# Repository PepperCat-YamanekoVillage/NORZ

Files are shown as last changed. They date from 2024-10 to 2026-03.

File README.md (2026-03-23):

# NORZ

NORZ is a project to create a Z80-compatible CPU using only NOR gates.

</br>

The project is progressing according to the following roadmap:
- [x] Draft the CPU design based on the Z80 specifications
- [x] Write the Verilog code
- [x] Debug the Verilog code
- [x] Implement the design on boards
- [x] Make a test board
- [x] Test the test board
- [ ] Debug the boards

</br>

### My blogs (ja)

[Gates consisting of NOR](https://yamanekovillage.com/articles/norz_1/)

[Modules consisting of NOR](https://yamanekovillage.com/articles/norz_2/)

[NORZ(Z80)\'s architecture](https://yamanekovillage.com/articles/norz_3/)

[NORZ on Verilog](https://yamanekovillage.com/articles/norz_4/)

[Debuging Verilog codes](https://yamanekovillage.com/articles/norz_5/)

[Design PCBs](https://yamanekovillage.com/articles/norz_6/)

[Make a test board (Failed)](https://yamanekovillage.com/articles/norz_7/)

</br>

## Confirmed instructions in Verilog

### 8-Bit Load Group
- [x] LD r,r’
- [x] LD r,n
- [x] LD r,(HL)
- [x] LD r,(IX+d)
- [x] LD r,(IY+d)
- [x] LD (HL),r
- [x] LD (IX+d),r
- [x] LD (IY+d),r
- [x] LD (HL),n
- [x] LD (IX+d),n
- [x] LD (IY+d),n
- [x] LD A,(BC)
- [x] LD A,(DE)
- [x] LD A,(nn)
- [x] LD (BC),A
- [x] LD (DE),A
- [x] LD (nn),A
- [x] LD A,I
- [x] LD A,R
- [x] LD I,A
- [x] LD R,A

### 16-Bit Load Group
- [x] LD dd,nn
- [x] LD IX,nn
- [x] LD IY,nn
- [x] LD HL,(nn)
- [x] LD dd,(nn)
- [x] LD IX,(nn)
- [x] LD IY,(nn)
- [x] LD (nn),HL
- [x] LD (nn),dd
- [x] LD (nn),IX
- [x] LD (nn),IY
- [x] LD SP,HL
- [x] LD SP,IX
- [x] LD SP,IY
- [x] PUSH qq
- [x] PUSH IX
- [x] PUSH IY
- [x] POP qq
- [x] POP IX
- [x] POP IY

### Exchange, Block Transfer, and Search Group
- [x] EX DE,HL
- [x] EX AF,AF
- [x] EXX
- [x] EX (SP),HL
- [x] EX (SP),IX
- [x] EX (SP),IY
- [x] LDI
- [x] LDIR
- [x] LDD
- [x] LDDR
- [x] CPI
- [x] CPIR
- [x] CPD
- [x] CPDR

### 8-Bit Arithmetic Group
- [x] ADD A,r
- [x] ADD A,n
- [x] ADD A,(HL)
- [x] ADD A,(IX+d)
- [x] ADD A,(IY+d)
- [x] ADC A,r
- [x] ADC A,n
- [x] ADC A,(HL)
- [x] ADC A,(IX+d)
- [x] ADC A,(IY+d)
- [x] SUB r
- [x] SUB n
- [x] SUB (HL)
- [x] SUB (IX+d)
- [x] SUB (IY+d)
- [x] SBC r
- [x] SBC n
- [x] SBC (HL)
- [x] SBC (IX+d)
- [x] SBC (IY+d)
- [x] AND r
- [x] AND n
- [x] AND (HL)
- [x] AND (IX+d)
- [x] AND (IY+d)
- [x] OR r
- [x] OR n
- [x] OR (HL)
- [x] OR (IX+d)
- [x] OR (IY+d)
- [x] XOR r
- [x] XOR n
- [x] XOR (HL)
- [x] XOR (IX+d)
- [x] XOR (IY+d)
- [x] CP r
- [x] CP n
- [x] CP (HL)
- [x] CP (IX+d)
- [x] CP (IY+d)
- [x] INC r
- [x] INC (HL)
- [x] INC (IX+d)
- [x] INC (IY+d)
- [x] DEC r
- [x] DEC (HL)
- [x] DEC (IX+d)
- [x] DEC (IY+d)

### General-Purpose Arithmetic and CPU Control Groups
- [x] DAA
- [x] CPL
- [x] NEG
- [x] CCF
- [x] SCF
- [x] NOP
- [x] HALT
- [x] DI
- [x] EI
- [x] IM 0
- [x] IM 1
- [x] IM 2

### 16-Bit Arithmetic Group
- [x] ADD HL,ss
- [x] ADC HL,ss
- [x] SBC HL,ss
- [x] ADD IX,pp
- [x] ADD IY,rr
- [x] INC ss
- [x] INC IX
- [x] INC IY
- [x] DEC ss
- [x] DEC IX
- [x] DEC IY

### Rotate and Shift Group
- [x] RLCA
- [x] RLA
- [x] RRCA
- [x] RRA
- [x] RLC r
- [x] RLC (HL)
- [x] RLC (IX+d)
- [x] RLC (IY+d)
- [x] RL r
- [x] RL (HL)
- [x] RL (IX+d)
- [x] RL (IY+d)
- [x] RRC r
- [x] RRC (HL)
- [x] RRC (IX+d)
- [x] RRC (IY+d)
- [x] RR r
- [x] RR (HL)
- [x] RR (IX+d)
- [x] RR (IY+d)
- [x] SLA r
- [x] SLA (HL)
- [x] SLA (IX+d)
- [x] SLA (IY+d)
- [x] SRA r
- [x] SRA (HL)
- [x] SRA (IX+d)
- [x] SRA (IY+d)
- [x] SRL r
- [x] SRL (HL)
- [x] SRL (IX+d)
- [x] SRL (IY+d)
- [x] RLD
- [x] RRD

### Bit Set, Reset, and Test Group
- [x] BIT b,r
- [x] BIT b,(HL)
- [x] BIT b,(IX+d)
- [x] BIT b,(IY+d)
- [x] SET b,r
- [x] SET b,(HL)
- [x] SET b,(IX+d)
- [x] SET b,(IY+d)
- [x] RES b,r
- [x] RES b,(HL)
- [x] RES b,(IX+d)
- [x] RES b,(IY+d)

### Jump Group
- [x] JP nn
- [x] JP cc,nn
- [x] JR e
- [x] JR C,e
- [x] JR NC,e
- [x] JR Z,e
- [x] JR NZ,e
- [x] JP (HL)
- [x] JP (IX)
- [x] JP (IY)
- [x] DJNZ e

### Call and Return Group
- [x] CALL nn
- [x] CALL cc,nn
- [x] RET
- [x] RET cc
- [x] RETI
- [x] RETN
- [x] RST p

### Input and Output Group
- [x] IN A,(n)
- [x] IN r,(C)
- [x] INI
- [x] INIR
- [x] IND
- [x] INDR
- [x] OUT (n),A
- [x] OUT (C),r
- [x] OUTI
- [x] OTIR
- [x] OUTD
- [x] OTDR

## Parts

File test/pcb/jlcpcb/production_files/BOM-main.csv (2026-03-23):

Comment | Designator | Footprint | LCSC | Quantity
0.5K-DHQX-60PWB | U1 | FPC-SMD_60P-P0.50_HDGC_0.5K-DHQX-60PWB | C5292476 | 1
Screw_Terminal_01x02 | J2 | TerminalBlock_bornier-2_P5.08mm |  | 1
MEGA BOTTOM | J1 | MEGA2560_PRO_MINI |  | 1

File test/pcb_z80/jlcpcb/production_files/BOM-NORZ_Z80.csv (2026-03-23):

Comment | Designator | Footprint | LCSC | Quantity
0.5K-DHQX-60PWB | U1 | FPC-SMD_60P-P0.50_HDGC_0.5K-DHQX-60PWB | C5292476 | 1
22nF | C2 | C_0603_1608Metric |  | 1
100nF | C1 | C_0603_1608Metric |  | 1
Z84C00xxP | U2 | DIP-40_W15.24mm |  | 1

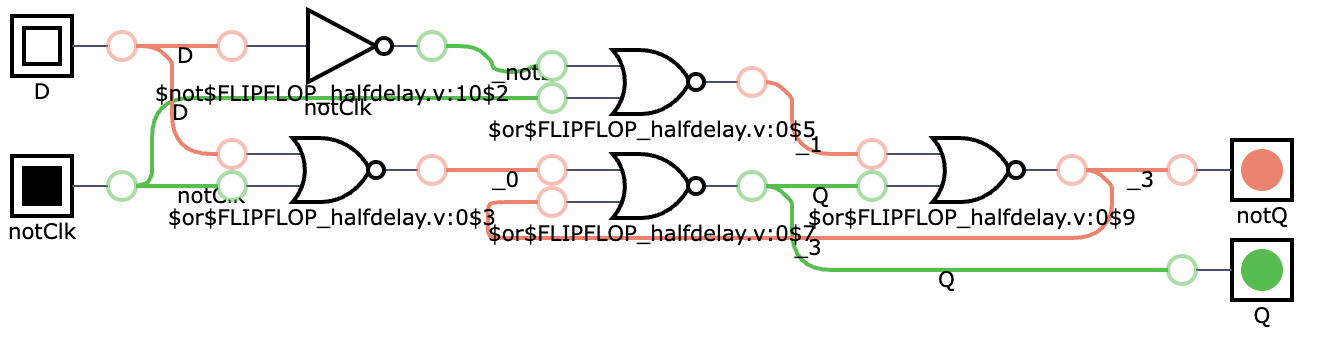
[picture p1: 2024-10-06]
flipflop/parts/.halfdelay.png

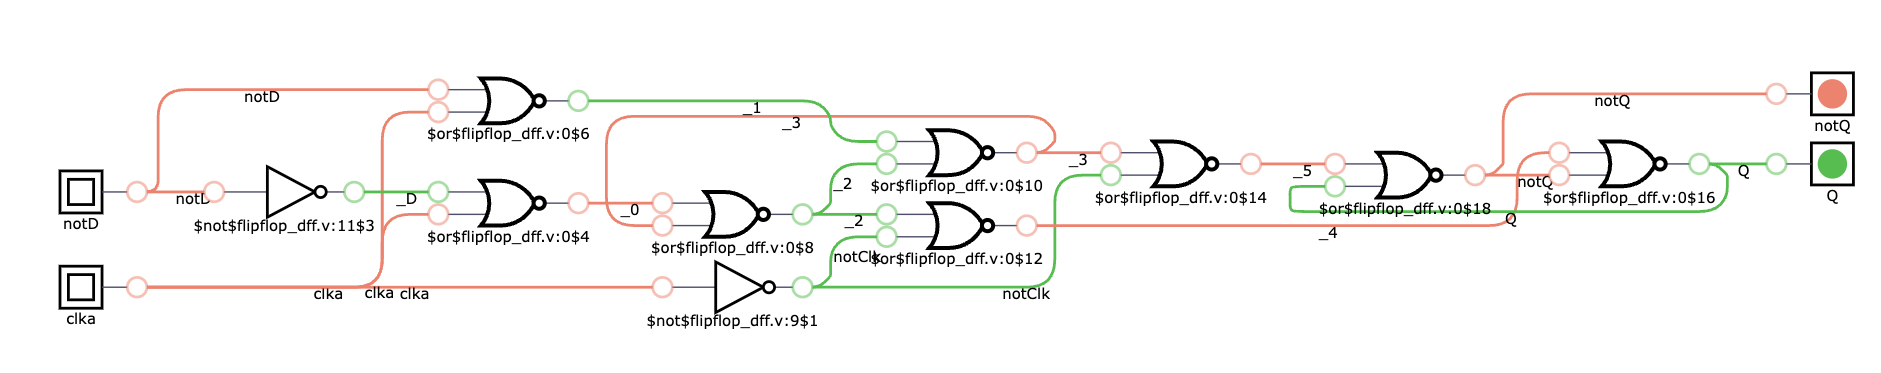
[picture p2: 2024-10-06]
verilog/flipflop/parts/.dff.png

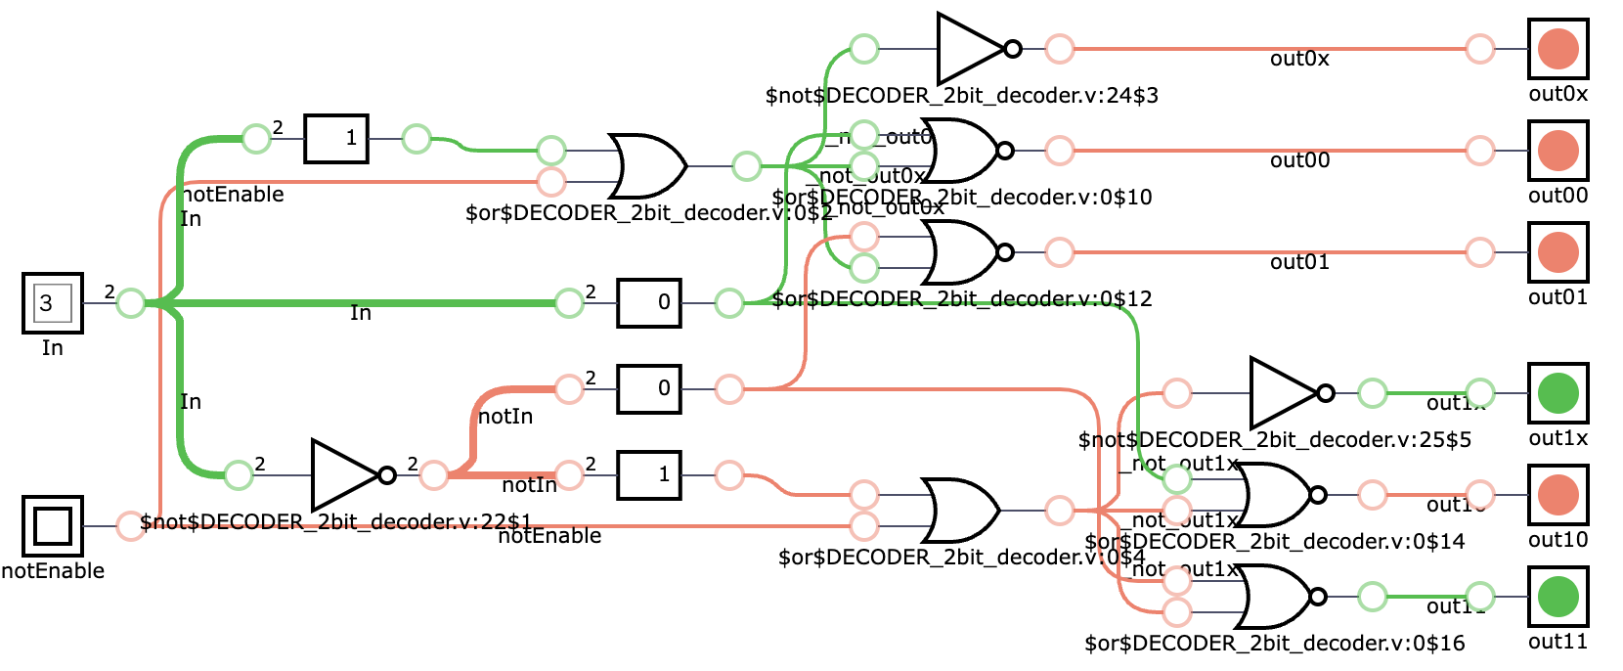
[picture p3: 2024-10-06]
verilog/decoder/parts/.2bit_decoder.png

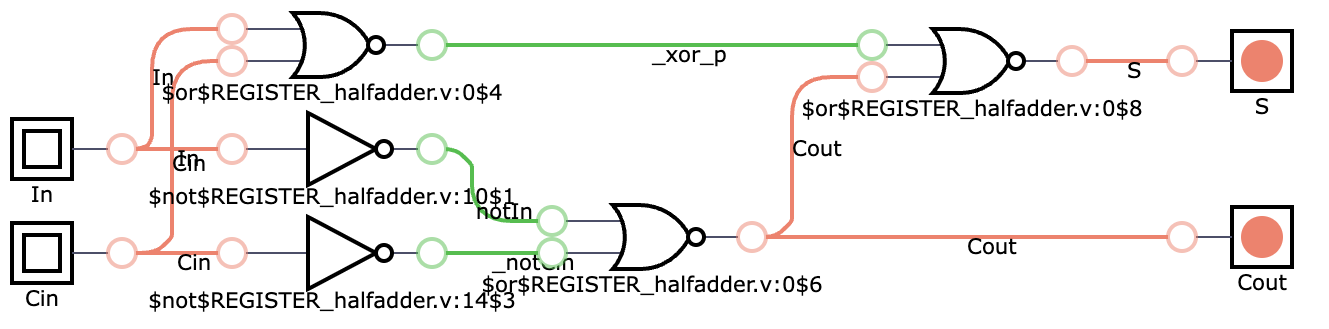
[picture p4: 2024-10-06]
register/parts/.half_adder_inc.png

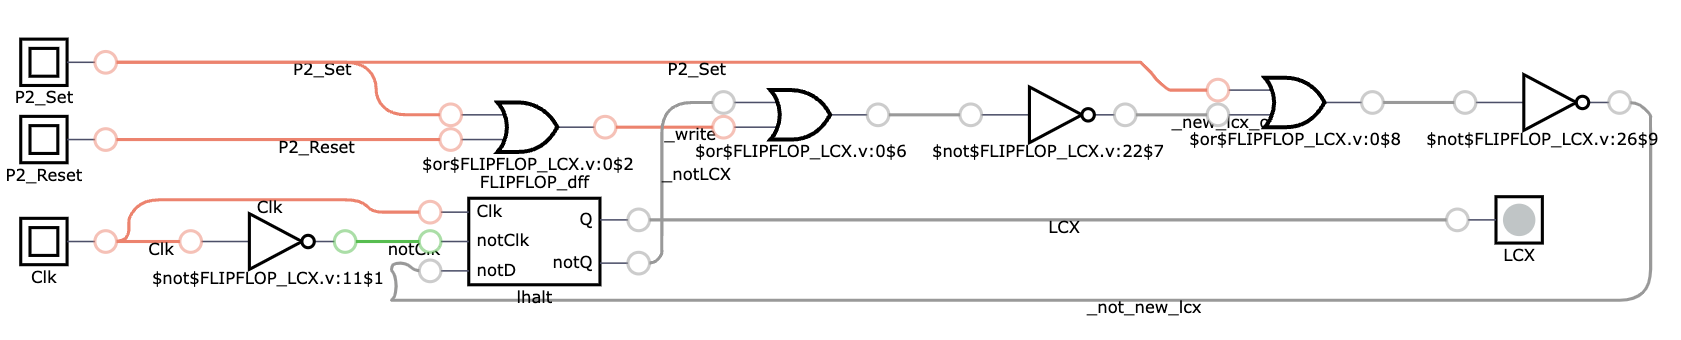
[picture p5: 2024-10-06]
verilog/flipflop/parts/.dff_LCX.png

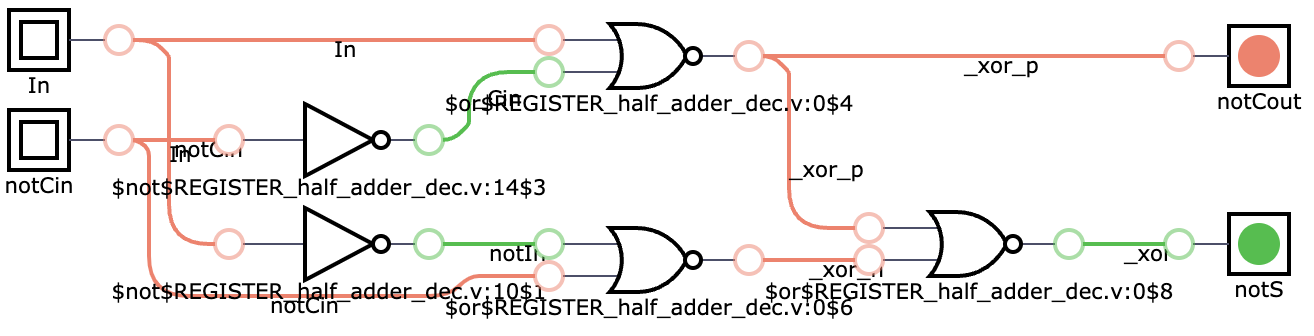
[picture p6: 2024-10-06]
register/parts/.half_adder_dec.png

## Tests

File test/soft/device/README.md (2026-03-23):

# Device Firmware (PlatformIO)

Arduino Mega2560 firmware that hosts a Z80 bus cycle runner.

## Build

```bash
cd device
pio run
```

## Upload

```bash
cd device
pio run --target upload
pio device monitor --baud 115200
```

## Serial Commands

- `PING`
- `RESET`
- `DATA_SRC <D|O>`
- `CLK_US <halfCycleUs>`
- `CLEAR [byteHex]`
- `LOAD <addrHex> <b0> <b1> ...`
- `RUN <cyclesDec>`
- `STEP`
- `SNAP`
- `MEM <addrHex> <lenHex>`
- `TRACE`
- `WTRACE`

All responses are single-line ASCII.

`DATA_SRC` selects which bus is used when reading Z80 write data:
- `D`: read from D0-D7 pins (default)
- `O`: read from Dout0-Dout7 pins

`CLK_US` sets half-cycle length in microseconds (default: 20).

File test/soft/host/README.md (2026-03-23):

# Host Runner (Mega2560 + Z80)

This script drives the Mega2560 firmware over serial and runs text tests from `_test/tests_txt`.

## Setup

```bash
cd host
python -m venv .venv
source .venv/bin/activate
pip install -r requirements.txt
```

## Run

```bash
python run_tests.py --port /dev/ttyACM0 --tests ../_test/tests_txt --filter MEGA --data-src D --half-cycle-us 20 --cycles 300
```

## Make Targets

```bash
make run                 # default run
make test                # run all tests, save to log-test-all.txt
make expand              # run by category, save log25-*.txt
make debug               # focused IO/BIT run, save log34-*.txt
```

You can override serial port and options:

```bash
make test PORT=/dev/cu.usbserial-1140 RUN_OPTS="--half-cycle-us 100 --cycles 300"
```

## Notes

- Current runner evaluates `PC=` assertions via M1 trace and memory assertions via `(<addr>)=<value>`.
- Use `--strict-reg` to enforce register/flag assertions (`A..L`, `IX/IY/SP`, `F`, `FlagS/Z/H/PV/N/C`, `I`, `R`, `LHALT`) via firmware command `CAPREG`.
- Default mode keeps compatibility with previous behavior (memory + PC assertions), and does not fail tests when snapshot capture is unavailable.
- `IMFa`, `IMFb`, `IFF1`, `IFF2` are parsed but not enforced by default because they are not directly exposed by the current snapshot protocol.
- `--data-src` selects write-data input source (`D`=D bus default, `O`=Dout bus).
- `--half-cycle-us` controls bus speed; increase this if write/read sampling is unstable.

Debug write trace for `MEGA/LD (nn),HL write`:

```bash
python run_tests.py --port /dev/ttyACM0 --filter MEGA --debug-ldnnhl
```

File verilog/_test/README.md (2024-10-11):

# How2debug

install coctb
```
py -m venv .venv
source .venv/bin/activate
py -m pip install cocotb
```

run make
```
make
```

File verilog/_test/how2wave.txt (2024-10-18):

rm -f sim_build;source .venv/bin/activate;make>log.txt;gtkwave sim_build/NORZ.fst

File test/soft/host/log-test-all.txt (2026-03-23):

PASS AR16/ADC HL,ss.txt
PASS AR16/ADD HL,ss.txt
PASS AR16/ADD IX,pp.txt
PASS AR16/ADD IY,rr.txt
PASS AR16/DEC IX.txt
PASS AR16/DEC IY.txt
PASS AR16/DEC ss.txt
PASS AR16/INC IX.txt
PASS AR16/INC IY.txt
PASS AR16/INC ss.txt
PASS AR16/SBC HL,ss.txt
PASS AR8/ADC A,(HL).txt
PASS AR8/ADC A,(IX+d).txt
PASS AR8/ADC A,(IY+d).txt
PASS AR8/ADC A,n.txt
PASS AR8/ADC A,r.txt
PASS AR8/ADD A,(HL).txt
PASS AR8/ADD A,(IX+d).txt
PASS AR8/ADD A,(IY+d).txt
PASS AR8/ADD A,n.txt
PASS AR8/ADD A,r.txt
PASS AR8/AND (HL).txt
PASS AR8/AND (IX+d).txt
PASS AR8/AND (IY+d).txt
PASS AR8/AND n.txt
PASS AR8/AND r.txt
PASS AR8/CP (HL).txt
PASS AR8/CP (IX+d).txt
PASS AR8/CP (IY+d).txt
PASS AR8/CP n.txt
PASS AR8/CP r.txt
PASS AR8/DEC (HL).txt
PASS AR8/DEC (IX+d).txt
PASS AR8/DEC (IY+d).txt
PASS AR8/DEC r.txt
PASS AR8/INC (HL).txt
PASS AR8/INC (IX+d).txt
PASS AR8/INC (IY+d).txt
PASS AR8/INC r.txt
PASS AR8/OR (HL).txt
PASS AR8/OR (IX+d).txt
PASS AR8/OR (IY+d).txt
PASS AR8/OR n.txt
PASS AR8/OR r.txt
PASS AR8/SBC (HL).txt
PASS AR8/SBC (IX+d).txt
PASS AR8/SBC (IY+d).txt
PASS AR8/SBC n.txt
PASS AR8/SBC r.txt
PASS AR8/SUB (HL).txt
PASS AR8/SUB (IX+d).txt
PASS AR8/SUB (IY+d).txt
PASS AR8/SUB n.txt
PASS AR8/SUB r.txt
PASS AR8/XOR (HL).txt
PASS AR8/XOR (IX+d).txt
PASS AR8/XOR (IY+d).txt
PASS AR8/XOR n.txt
PASS AR8/XOR r.txt
PASS BIT/BIT b,(HL).txt
PASS BIT/BIT b,(IX+d).txt
PASS BIT/BIT b,(IY+d).txt
PASS BIT/BIT b,r.txt
PASS BIT/RES b,(HL).txt
PASS BIT/RES b,(IX+d).txt
PASS BIT/RES b,(IY+d).txt
PASS BIT/RES b,r.txt
PASS BIT/SET b,(HL).txt
PASS BIT/SET b,(IX+d).txt
PASS BIT/SET b,(IY+d).txt
PASS BIT/SET b,r.txt
PASS CR/CALL cc,nn - c.txt
PASS CR/CALL cc,nn - nc.txt
PASS CR/CALL cc,nn - npv.txt
PASS CR/CALL cc,nn - ns.txt
PASS CR/CALL cc,nn - nz.txt
PASS CR/CALL cc,nn - pv.txt
PASS CR/CALL cc,nn - s.txt
PASS CR/CALL cc,nn - z.txt
PASS CR/CALL nn.txt
PASS CR/RET cc - c.txt
PASS CR/RET cc - nc.txt
PASS CR/RET cc - npv.txt
PASS CR/RET cc - ns.txt
PASS CR/RET cc - nz.txt
PASS CR/RET cc - pv.txt
PASS CR/RET cc - s.txt
PASS CR/RET cc - z.txt
PASS CR/RET.txt
PASS CR/RETI.txt
PASS CR/RST p - 0.txt
PASS CR/RST p - 1.txt
PASS CR/RST p - 2.txt
PASS CR/RST p - 3.txt
PASS CR/RST p - 4.txt
PASS CR/RST p - 5.txt
PASS CR/RST p - 6.txt
PASS CR/RST p - 7.txt
PASS EX/CPD.txt
PASS EX/CPDR.txt
PASS EX/CPI.txt
PASS EX/CPIR.txt
PASS EX/EX (SP),HL.txt
PASS EX/EX (SP),IX.txt
PASS EX/EX (SP),IY.txt
PASS EX/EX AF,AF.txt
PASS EX/EX DE,HL.txt
PASS EX/EXX.txt
PASS EX/LDD.txt
PASS EX/LDDR.txt
PASS EX/LDI.txt
PASS EX/LDIR.txt
PASS GAR/CCF.txt
PASS GAR/CPL.txt
PASS GAR/DAA.txt
PASS GAR/DI.txt
PASS GAR/EI.txt
PASS GAR/HALT.txt
PASS GAR/IM 0.txt
PASS GAR/IM 1.txt
PASS GAR/IM 2.txt
PASS GAR/NEG.txt
PASS GAR/NOP.txt
PASS GAR/SCF.txt
PASS IO/IN A,(n).txt
PASS IO/IN r,(C).txt
PASS IO/IND.txt
PASS IO/INDR.txt
PASS IO/INI.txt
PASS IO/INIR.txt
PASS IO/OTDR.txt
PASS IO/OTIR.txt
PASS IO/OUT (C),r.txt
PASS IO/OUT (n),A.txt
PASS IO/OUTD.txt
PASS IO/OUTI.txt
PASS JP/DJNZ e.txt
PASS JP/JP (HL).txt
PASS JP/JP (IX).txt
PASS JP/JP (IY).txt
PASS JP/JP cc,nn - c.txt
PASS JP/JP cc,nn - nc.txt
PASS JP/JP cc,nn - npv.txt
PASS JP/JP cc,nn - ns.txt
PASS JP/JP cc,nn - nz.txt
PASS JP/JP cc,nn - pv.txt
PASS JP/JP cc,nn - s.txt
PASS JP/JP cc,nn - z.txt
PASS JP/JP nn.txt
PASS JP/JR C,e.txt
PASS JP/JR NC,e.txt
PASS JP/JR NZ,e.txt
PASS JP/JR Z,e.txt
PASS JP/JR e - minus.txt
PASS JP/JR e - plus.txt
PASS LD16/LD (nn),HL.txt
PASS LD16/LD (nn),IX.txt
PASS LD16/LD (nn),IY.txt
PASS LD16/LD (nn),dd.txt
PASS LD16/LD HL,(nn).txt
PASS LD16/LD IX,(nn).txt
PASS LD16/LD IX,nn.txt
PASS LD16/LD IY,(nn).txt
PASS LD16/LD IY,nn.txt
PASS LD16/LD SP,HL.txt
PASS LD16/LD SP,IX.txt
PASS LD16/LD SP,IY.txt
PASS LD16/LD dd,(nn).txt
PASS LD16/LD dd,nn.txt
PASS LD16/PUSH IX | POP IX.txt
PASS LD16/PUSH IY | POP IY.txt
PASS LD16/PUSH qq | POP qq.txt
PASS LD8/LD (BC),A.txt
PASS LD8/LD (DE),A.txt
PASS LD8/LD (HL),n.txt
PASS LD8/LD (HL),r.txt
PASS LD8/LD (IX+d),n.txt
PASS LD8/LD (IX+d),r.txt
PASS LD8/LD (IY+d),n.txt
PASS LD8/LD (IY+d),r.txt
PASS LD8/LD (nn),A.txt
PASS LD8/LD A,(BC).txt
PASS LD8/LD A,(DE).txt
PASS LD8/LD A,(nn).txt
PASS LD8/LD A,I.txt
PASS LD8/LD A,R.txt
PASS LD8/LD I,A.txt
PASS LD8/LD R,A.txt
PASS LD8/LD r,(HL).txt
PASS LD8/LD r,(IX+d).txt
PASS LD8/LD r,(IY+d).txt
PASS LD8/LD r,n.txt
PASS LD8/LD r,r.txt
PASS MEGA/JP loop 0000.txt
PASS MEGA/LD (nn),HL write.txt
PASS ROT/RL (HL).txt
PASS ROT/RL (IX+d).txt
PASS ROT/RL (IY+d).txt
PASS ROT/RL r.txt
PASS ROT/RLA.txt
PASS ROT/RLC (HL).txt
PASS ROT/RLC (IX+d).txt
PASS ROT/RLC (IY+d).txt
PASS ROT/RLC r.txt
PASS ROT/RLCA.txt
PASS ROT/RLD.txt
PASS ROT/RR (HL).txt
PASS ROT/RR (IX+d).txt
PASS ROT/RR (IY+d).txt
PASS ROT/RR r.txt
PASS ROT/RRA.txt
PASS ROT/RRC (HL).txt
PASS ROT/RRC (IX+d).txt
PASS ROT/RRC (IY+d).txt
PASS ROT/RRC r.txt
PASS ROT/RRCA.txt
PASS ROT/RRD.txt
PASS ROT/SLA (HL).txt
PASS ROT/SLA (IX+d).txt
PASS ROT/SLA (IY+d).txt
PASS ROT/SLA r.txt
PASS ROT/SRA (HL).txt
PASS ROT/SRA (IX+d).txt
PASS ROT/SRA (IY+d).txt
PASS ROT/SRA r.txt
PASS ROT/SRL (HL).txt
PASS ROT/SRL (IX+d).txt
PASS ROT/SRL (IY+d).txt
PASS ROT/SRL r.txt
PASS _INTERRUPT/BUSRQ.txt
PASS _INTERRUPT/INT - 0CALL.txt
PASS _INTERRUPT/INT - 0RST.txt
PASS _INTERRUPT/INT - 1.txt
PASS _INTERRUPT/INT - 2.txt
PASS _INTERRUPT/NMI - di.txt
PASS _INTERRUPT/NMI - ei.txt
PASS _SAMPLE/divide.txt
PASS _SAMPLE/multiply.txt

Result: passed=238 failed=0

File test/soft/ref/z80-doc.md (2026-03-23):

---
title: NORだけでZ80互換CPUをつくる 〜 仕様決め 〜
description: NORゲートだけでCPUをつくるため、Z80の仕様を確認し、どんなふうに回路をつくればちゃんと動作しそうかの仕様決めをしました
slug: norz_3
thumbnail_url: "https://media.yamanekovillage.com/norz_3"
category: create
createdAt: 2024/08/25
modifiedAt: 2025/06/13
writer: 山椒ねこまんま
draft: false
---

1ヶ月ほどかかってようやく仕様が決まりました。いや〜長かった。202コも命令があるのでなかなか大変でしたよ。

もっとも、まだ実際に回路をつくってテストしたわけではないのでこれから変更される可能性もあるのですがね。

なお、仕様決定にあたり以下の本やページを参考にしました。とても参考になりました。ありがとうございます。\
{{< link
    "https://ndlsearch.ndl.go.jp/books/R100000002-I000001418670"
    "https://ndlsearch.ndl.go.jp/books/R100000002-I000001418670">}}\
{{< link
    "http://www.zilog.com/docs/z80/um0080.pdf"
    "http://www.zilog.com/docs/z80/um0080.pdf">}}\
{{< link
    "https://www.zilog.com/docs/z80/ps0178.pdf"
    "https://www.zilog.com/docs/z80/ps0178.pdf">}}\
{{< link
    "http://www.z80.info/zip/z80-interrupts.pdf"
    "http://www.z80.info/zip/z80-interrupts.pdf">}}\
{{< link
    "http://www.kazumi-kikou.com/pdf/TMPZ84C00AP.pdf"
    "http://www.kazumi-kikou.com/pdf/TMPZ84C00AP.pdf">}}\
{{< link
    "http://www.maroon.dti.ne.jp/youkan/mz700/z80cycle.html"
    "http://www.maroon.dti.ne.jp/youkan/mz700/z80cycle.html">}}\
{{< link
    "http://mydocuments.g2.xrea.com/html/p6/z80ref.html"
    "http://mydocuments.g2.xrea.com/html/p6/z80ref.html">}}

{{< toc >}}
インターフェース{#interface}
レジスタ{#register}
  - 公式{#rg-official}
  - 非公式{#rg-unofficial}
フリップフロップ{#flipflop}
  - 公式{#ff-official}
  - 非公式{#ff-unofficial}
パスフラグ{#pathflag}
  - レジスタ{#pf-pr}
  - フラグ{#pf-pf}
  - フリップフロップ{#pf-p2}
  - ALU{#pf-pa}
  - インターフェース{#pf-pi}
  - 半遅延インターフェース{#pf-phi}
  - 遅延{#pf-pai}
ALU{#alu}
  - 演算{#alu-operation}
  - 出力バス{#alu-bus}
デコーダ{#decoder}
  - 標準サイクル{#basecycle}
    - M1{#bc-m1}
    - MR{#bc-mr}
    - MA{#bc-ma}
    - R{#bc-r}
    - RA{#bc-ra}
    - W{#bc-w}
    - I{#bc-i}
    - O{#bc-o}
  - 割り込みサイクル{#interruptcycle}
    - マスク可能割り込み{#ic-int}
    - マスク不能割り込み{#ic-nmi}
    - バス要求{#ic-busrq}
    - リセット{#ic-reset}
  - 命令{#instruction}
    - 8bitデータ移動{#in-8ld}
      - LD r,r’{#in-LDrr}
      - LD r,n{#in-LDrn}
      - LD r,(HL){#in-LDrqHLp}
      - LD r,(IX+d){#in-LDrqIXtdp}
      - LD r,(IY+d){#in-LDrqIYtdp}
      - LD (HL),r{#in-LDqHLpr}
      - LD (IX+d),r{#in-LDqIXtdpr}
      - LD (IY+d),r{#in-LDqIYtdpr}
      - LD (HL),n{#in-LDqHLpn}
      - LD (IX+d),n{#in-LDqIXtdpn}
      - LD (IY+d),n{#in-LDqIYtdpn}
      - LD A,(BC){#in-LDAqBCp}
      - LD A,(DE){#in-LDAqDEp}
      - LD A,(nn){#in-LDAqnnp}
      - LD (BC),A{#in-LDqBCpA}
      - LD (DE),A{#in-LDqDEpA}
      - LD (nn),A{#in-LDqnnpA}
      - LD A,I{#in-LDAI}
      - LD A,R{#in-LDAR}
      - LD I,A{#in-LDIA}
      - LD R,A{#in-LDRA}
    - 16bitデータ移動{#in-16ld}
      - LD dd,nn{#in-LDddnn}
      - LD IX,nn{#in-LDIXnn}
      - LD IY,nn{#in-LDIYnn}
      - LD HL,(nn){#in-LDHLqnnp}
      - LD dd,(nn){#in-LDddqnnp}
      - LD IX,(nn){#in-LDIXqnnp}
      - LD IY,(nn){#in-LDIYqnnp}
      - LD (nn),HL{#in-LDqnnpHL}
      - LD (nn),dd{#in-LDqnnpdd}
      - LD (nn),IX{#in-LDqnnpIX}
      - LD (nn),IY{#in-LDqnnpIY}
      - LD SP,HL{#in-LDSPHL}
      - LD SP,IX{#in-LDSPIX}
      - LD SP,IY{#in-LDSPIY}
      - PUSH qq{#in-PUSHqq}
      - PUSH IX{#in-PUSHIX}
      - PUSH IY{#in-PUSHIY}
      - POP qq{#in-POPqq}
      - POP IX{#in-POPIX}
      - POP IY{#in-POPIY}
    - 交換・ブロック転送および検索{#in-ex}
      - EX DE,HL{#in-EXDEHL}
      - EX AF,A’F’{#in-EXAFAF}
      - EXX{#in-EXX}
      - EX (SP),HL{#in-EXqSPpHL}
      - EX (SP),IX{#in-EXqSPpIX}
      - EX (SP),IY{#in-EXqSPpIY}
      - LDI{#in-LDI}
      - LDIR{#in-LDIR}
      - LDD{#in-LDD}
      - LDDR{#in-LDDR}
      - CPI{#in-CPI}
      - CPIR{#in-CPIR}
      - CPD{#in-CPD}
      - CPDR{#in-CPDR}
    - 8bit算術・論理演算{#in-8ari}
      - ADD A,r{#in-ADDAr}
      - ADD A,n{#in-ADDAn}
      - ADD A,(HL){#in-ADDAqHLp}
      - ADD A,(IX+d){#in-ADDAqIXtdp}
      - ADD A,(IY+d){#in-ADDAqIYtdp}
      - ADC A,r{#in-ADCAr}
      - ADC A,n{#in-ADCAn}
      - ADC A,(HL){#in-ADCAqHLp}
      - ADC A,(IX+d){#in-ADCAqIXtdp}
      - ADC A,(IY+d){#in-ADCAqIYtdp}
      - SUB A,r{#in-SUBAr}
      - SUB A,n{#in-SUBAn}
      - SUB A,(HL){#in-SUBAqHLp}
      - SUB A,(IX+d){#in-SUBAqIXtdp}
      - SUB A,(IY+d){#in-SUBAqIYtdp}
      - SBC A,r{#in-SBCAr}
      - SBC A,n{#in-SBCAn}
      - SBC A,(HL){#in-SBCAqHLp}
      - SBC A,(IX+d){#in-SBCAqIXtdp}
      - SBC A,(IY+d){#in-SBCAqIYtdp}
      - AND A,r{#in-ANDAr}
      - AND A,n{#in-ANDAn}
      - AND A,(HL){#in-ANDAqHLp}
      - AND A,(IX+d){#in-ANDAqIXtdp}
      - AND A,(IY+d){#in-ANDAqIYtdp}
      - OR A,r{#in-ORAr}
      - OR A,n{#in-ORAn}
      - OR A,(HL){#in-ORAqHLp}
      - OR A,(IX+d){#in-ORAqIXtdp}
      - OR A,(IY+d){#in-ORAqIYtdp}
      - XOR A,r{#in-XORAr}
      - XOR A,n{#in-XORAn}
      - XOR A,(HL){#in-XORAqHLp}
      - XOR A,(IX+d){#in-XORAqIXtdp}
      - XOR A,(IY+d){#in-XORAqIYtdp}
      - CP A,r{#in-CPAr}
      - CP A,n{#in-CPAn}
      - CP A,(HL){#in-CPAqHLp}
      - CP A,(IX+d){#in-CPAqIXtdp}
      - CP A,(IY+d){#in-CPAqIYtdp}
      - INC r{#in-INCr}
      - INC (HL){#in-INCqHLp}
      - INC (IX+d){#in-INCqIXtdp}
      - INC (IY+d){#in-INCqIYtdp}
      - DEC r{#in-DECr}
      - DEC (HL){#in-DECqHLp}
      - DEC (IX+d){#in-DECqIXtdp}
      - DEC (IY+d){#in-DECqIYtdp}
    - 汎用算術演算およびCPU制御{#in-gpa}
      - DAA{#in-DAA}
      - CPL{#in-CPL}
      - NEG{#in-NEG}
      - CCF{#in-CCF}
      - SCF{#in-SCF}
      - NOP{#in-NOP}
      - HALT{#in-HALT}
      - DI{#in-DI}
      - EI{#in-EI}
      - IM 0{#in-IM0}
      - IM 1{#in-IM1}
      - IM 2{#in-IM2}
    - 16bit算術演算{#in-16ari}
      - ADD HL,ss{#in-ADDHLss}
      - ADC HL,ss{#in-ADCHLss}
      - SBC HL,ss{#in-SBCHLss}
      - ADD IX,pp{#in-ADDIXpp}
      - ADD IY,rr{#in-ADDIYrr}
      - INC ss{#in-INCss}
      - INC IX{#in-INCIX}
      - INC IY{#in-INCIY}
      - DEC ss{#in-DECss}
      - DEC IX{#in-DECIX}
      - DEC IY{#in-DECIY}
    - 循環および桁移動{#in-rot}
      - RLCA{#in-RLCA}
      - RLA{#in-RLA}
      - RRCA{#in-RRCA}
      - RRA{#in-RRA}
      - RLC r{#in-RLCr}
      - RLC (HL){#in-RLCqHLp}
      - RLC (IX+d){#in-RLCqIXtdp}
      - RLC (IY+d){#in-RLCqIYtdp}
      - RL r{#in-RLr}
      - RL (HL){#in-RLqHLp}
      - RL (IX+d){#in-RLqIXtdp}
      - RL (IY+d){#in-RLqIYtdp}
      - RRC r{#in-RRCr}
      - RRC (HL){#in-RRCqHLp}
      - RRC (IX+d){#in-RRCqIXtdp}
      - RRC (IY+d){#in-RRCqIYtdp}
      - RR r{#in-RRr}
      - RR (HL){#in-RRqHLp}
      - RR (IX+d){#in-RRqIXtdp}
      - RR (IY+d){#in-RRqIYtdp}
      - RLC r{#in-RLCr}
      - RLC (HL){#in-RLCqHLp}
      - RLC (IX+d){#in-RLCqIXtdp}
      - RLC (IY+d){#in-RLCqIYtdp}
      - SLA r{#in-SLAr}
      - SLA (HL){#in-SLAqHLp}
      - SLA (IX+d){#in-SLAqIXtdp}
      - SLA (IY+d){#in-SLAqIYtdp}
      - SRA r{#in-SRAr}
      - SRA (HL){#in-SRAqHLp}
      - SRA (IX+d){#in-SRAqIXtdp}
      - SRA (IY+d){#in-SRAqIYtdp}
      - SRL r{#in-SRLr}
      - SRL (HL){#in-SRLqHLp}
      - SRL (IX+d){#in-SRLqIXtdp}
      - SRL (IY+d){#in-SRLqIYtdp}
      - RLD{#in-RLD}
      - RRD{#in-RRD}
    - bit操作および判定{#in-bit}
      - BIT b,r{#in-BITbr}
      - BIT b,(HL){#in-BITbqHLp}
      - BIT b,(IX+d){#in-BITbqIXtdp}
      - BIT b,(IY+d){#in-BITbqIYtdp}
      - SET b,r{#in-SETbr}
      - SET b,(HL){#in-SETbqHLp}
      - SET b,(IX+d){#in-SETbqIXtdp}
      - SET b,(IY+d){#in-SETbqIYtdp}
      - RES b,r{#in-RESbr}
      - RES b,(HL){#in-RESbqHLp}
      - RES b,(IX+d){#in-RESbqIXtdp}
      - RES b,(IY+d){#in-RESbqIYtdp}
    - 飛び越し命令{#in-jmp}
      - JP nn{#in-JPnn}
      - JP cc,nn{#in-JPccnn}
      - JR e{#in-JRe}
      - JR C,e{#in-JRCe}
      - JR NC,e{#in-JRNCe}
      - JR Z,e{#in-JRZe}
      - JR NZ,e{#in-JRNZe}
      - JP (HL){#in-JPqHLp}
      - JP (IX){#in-JPqIXp}
      - JP (IY){#in-JPqIYp}
      - DJNZ e{#in-DJNZe}
    - サブルーチン接続および戻り命令{#in-sub}
      - CALL nn{#in-CALLnn}
      - CALL cc,nn{#in-CALLccnn}
      - RET{#in-RET}
      - RET cc{#in-RETcc}
      - RETI{#in-RETI}
      - RETN{#in-RETN}
      - RST p{#in-RSTp}
    - 入力および出力命令{#in-io}
      - IN A,(n){#in-INAqnp}
      - IN r,(C){#in-INrqCp}
      - INI{#in-INI}
      - INIR{#in-INIR}
      - IND{#in-IND}
      - INDR{#in-INDR}
      - OUT (n),A{#in-OUTqnpA}
      - OUT (C),r{#in-OUTqCpr}
      - OUTI{#in-OUTI}
      - OTIR{#in-OTIR}
      - OUTD{#in-OUTD}
      - OTDR{#in-OTDR}
命令分布{#instuructiontable}
  - X1{#it-x1}
  - XIX{#it-xix}
  - XIX4{#it-xix4}
  - XIY{#it-xiy}
  - XIY4{#it-xiy4}
  - XOTR{#it-xotr}
  - XBIT{#it-xbit}
{{< /toc >}}

## インターフェース{#interface}

{{<table5HM>}}
A: 種類
B: io
C: とりうる値
D: デフォルト値
E: 名前
items:
    - a: アドレスバス
      b: out
      c: 1/0/Z
      d: Z
      e: A0~A15
    - a: データバス
      b: in/out
      c: 1/0/Z
      d: Z
      e: D0~D7
    - a: バス制御
      b: in
      c: 
      d: 
      e: /BUSRQ
    - a: 
      b: out
      c: 1/0
      d: 1
      e: BUSAK
    - a: 主記憶制御
      b: out
      c: 1/0/Z
      d: 1
      e: /MREQ
    - a: 
      b: out
      c: 1/0/Z
      d: 1
      e: /RD
    - a: 
      b: out
      c: 1/0/Z
      d: 1
      e: /WR
    - a: 
      b: out
      c: 1/0
      d: 1
      e: /RFSH
    - a: 入出力制御
      b: out
      c: 1/0/Z
      d: 1
      e: /IORQ
    - a: その他の制御
      b: out
      c: 1/0
      d: 1
      e: /M1
    - a: 
      b: in
      c: 
      d: 
      e: /RESET
    - a: 
      b: in
      c: 
      d: 
      e: /WAIT
    - a: 
      b: out
      c: 1/0
      d: 1
      e: /HALT
    - a: 割り込み入力
      b: in
      c: 
      d: 
      e: /NMI
    - a: 
      b: in
      c: 
      d: 
      e: /INT
    - a: クロック
      b: in
      c: 
      d: 
      e: /CLK
    - a: 電源
      b: in
      c: 
      d: 
      e: VCC(5V)
    - a: 
      b: in
      c: 
      d: 
      e: GND
{{</table5HM>}}

<br>
{{<line>}}

## レジスタ{#register}

## 公式レジスタ{#rg-official}

### アキュムレータ (A)

8bit

EX系命令で交換できる

### フラグレジスタ (F)

8bit

EX系命令で交換できる\
フラグ書き込みが可能

{{<table8HM>}}
A: 第7bit
B: 第6bit
C: 第5bit
D: 第4bit
E: 第3bit
F: 第2bit
G: 第1bit
H: 第0bit
items:
    - a: S
      b: Z
      c: (X)
      d: H
      e: (Y)
      f: P/V
      g: "N"
      h: C
{{</table8HM>}}

S: ALUの結果が負\
Z: ALUの結果が0\
H: ALUにおいてハーフキャリー/ハーフボローが発生\
P: ALUの結果が偶パリティ\
V: ALUにおいてオーバーフローが発生\
N: ALUで減算を実行\
C: ALUにおいてキャリー/ボローが発生

キャリー・ボロー・ハーフキャリー・ハーフボロー・パリティ・オーバーフローについてはALUの項で解説します。

### 汎用レジスタ (B,C,D,E,H,L)

8bit

EX系命令で交換できる

### 裏レジスタ (A',F',B',C',D',E',H',L')

8bit

EX系命令で交換できる

### プログラムカウンタ (PC)

16bit

インクリメント可能

### スタックポインタ (SP)

16bit

インクリメント・デクリメント可能

### インデックスレジスタ (IX,IY)

16bit

### 割り込み番地指定レジスタ (I)

8bit

### リフレッシュレジスタ (R)

8bit

インクリメントが可能(ただし、第7bitは不変)

## 非公式レジスタ{#rg-unofficial}

### 命令1バイト経過Tサイクル (XPT)

5bit

クロックに合わせて自動でインクリメントしていく\
Write不可\
HaltとResetが可能

### データレジスタ (Dt,Dtex)

8bit

### 位相半ずらしデータレジスタ (Dtcs)

8bit

クロックがhighのときに、Dinから読み込みできる\
Write不可

### 命令レジスタ (OP,OPold)

8bit

WriteはOPのみ可能(lowが入る)\
OPからOPoldへのスライドが可能

<br>
{{<line>}}

## フリップフロップ{#flipflop}

## 公式フリップフロップ{#ff-official}

### IFF1/2

割り込み許可用

### IMFa/b

IM 0/1/2 で指定する割り込みモード用

{{<table3HM>}}
A: IMFa
B: IMFb
C: モード
items:
    - a: 0
      b: 0
      c: 0
    - a: 0
      b: 1
      c: NOT USED
    - a: 1
      b: 0
      c: 1
    - a: 1
      b: 1
      c: 2
{{</table3HM>}}

## 非公式フリップフロップ{#ff-unofficial}

### 検出系(T)

TINT:2 負論理 ↓入力と↑入力がある ↑入力は出力を半クロックずらす 使用時はAND\
TNMI:2 負論理 ↓入力と↑入力がある ↑入力は出力を半クロックずらす 使用時はAND\
TWAIT:1 負論理 ↑入力 寿命1サイクル\
TRSET:3 負論理 3サイクルカウント用 使用は3つ目

### 保持系(L)

LHALT: if(LHALT=1)→PI_Flag_HALT

### サイクル系(C)

XPTと組み合わせてパスフラグを出力する

CM1\
CMR\
CMA\
CBUSRQ\
CRESET\
CNMI\
CINT0\
CINT0_RST\
CINT0_CALL\
CINT1\
CINT2

### M1型命令系(X)

XIX(11 011 101): 1\
XIX4_0/1(XIX→11 001 011): 2\
XIY(11 111 101): 1\
XIY4_0/1(XIY→11 001 011): 2\
XOTR(11 101 101): 1\
XBIT(11 001 011): 1

### MR型命令系(I)

XPTと組み合わせてパスフラグを出力する\
全156のパスフラグを構成するため、8つのフリップフロップを使用

ILDrn_A/B/C/D/E/H/L: 7\
ILDr(IX+d)_A/B/C/D/E/H/L: 7\
ILDr(IY+d)_A/B/C/D/E/H/L: 7\
ILD(IX+d)r_A/B/C/D/E/H/L: 7\
ILD(IY+d)r_A/B/C/D/E/H/L: 7\
ILD(HL)n: 1\
ILD(IX+d)n_0/1: 2\
ILD(IY+d)n_0/1: 2\
ILDA(nn)_0/1: 2\
ILD(nn)A_0/1: 2\
ILDddnn_BC/DE/HL/SP_0/1: 8\
ILDIXnn_0/1: 2\
ILDIYnn_0/1: 2\
ILDHL(nn)_0/1: 2\
ILDdd(nn)_BC/DE/HL/SP_0/1: 8\
ILDIX(nn)_0/1: 2\
ILDIY(nn)_0/1: 2\
ILD(nn)HL_0/1: 2\
ILD(nn)dd_BC/DE/HL/SP_0/1: 8\
ILD(nn)IX_0/1: 2\
ILD(nn)IY_0/1: 2\
IADDAn: 1\
IADDA(IX+d): 1\
IADDA(IY+d): 1\
IADCAn: 1\
IADCA(IX+d): 1\
IADCA(IY+d): 1\
ISUBAn: 1\
ISUBA(IX+d): 1\
ISUBA(IY+d): 1\
ISBCAn: 1\
ISBCA(IX+d): 1\
ISBCA(IY+d): 1\
IANDn: 1\
IAND(IX+d): 1\
IAND(IY+d): 1\
IORn: 1\
IOR(IX+d): 1\
IOR(IY+d): 1\
IXORn: 1\
IXOR(IX+d): 1\
IXOR(IY+d): 1\
ICPn: 1\
ICP(IX+d): 1\
ICP(IY+d): 1\
IINC(IX+d): 1\
IINC(IY+d): 1\
IDEC(IX+d): 1\
IDEC(IY+d): 1\
IJPnn_0/1: 2\
IJPccnn_0/1/2/3/4/5/6/7_0/1: 16\
IJRe: 1\
IJRCe: 1\
IJRNCe: 1\
IJRZe: 1\
IJRNZe: 1\
IDJNZe: 1\
ICALLnn_0/1: 2\
ICALLccnn_0/1/2/3/4/5/6/7_0/1: 16\
IINA(n): 1\
IOUT(n)A: 1

ITABLE

<br>
{{<line>}}

## パスフラグ{#pathflag}

動作を決定する正負状態を表すものを言いたかったのですが、 **フラグ** という言葉を使えなかったのでパスフラグとでも呼称しておきます。

## レジスタ (PR){#pf-pr}

### 書き込み

Write_A: high\
Write_B: high\
Write_C: low\
Write_D: high\
Write_E: low\
Write_H: high\
Write_L: low\
Write_PC_high\
Write_PC_low\
Write_SP_high\
Write_SP_low\
Write_IX_high\
Write_IX_low\
Write_IY_high\
Write_IY_low\
Write_Dt: low\
Write_Dtex: high\
Write_R: low\
Write_I: high\
Write_OP: low InvertInの影響を受けない

### その他

Ex_AF_A’F’: AF↔︎A'F'\
Ex_DE_HL: DE↔︎HL\
Exx: BCDEHL↔︎B'C'D'E'H'L'\
Inc_PC\
Inc_SP\
Inc_R: R_7は不変\
Dec_SP\
Reset_XPT\
Halt_XPT\
SlideOP(OP→OPold)

## フラグ (PF){#pf-pf}

### 書き込み

いずれかが1の時、X<-ALU_5,Y<-ALU_3

Write_S\
Write_Z\
Write_H\
Write_P/V\
Write_N\
Write_C

### 入力選択

Select_S_bitZ\
Select_Z_bitZ\
Select_H_bitZ\
Select_P/V_bitZ\
Select_N_bitZ\
Select_C_bitZ

## フリップフロップ (P2){#pf-p2}

### 割り込み公式

Set_IFF1\
Set_IFF2\
Reset_IFF1\
Reset_IFF2\
EvacuateIFF: IFF2←IFF1\
RestoreIFF: IFF1←IFF2\
IM0\
IM1\
IM2

### 検出系(T)

Reset_TNMI: TNMI←1\
Reset_TINT: TINT←1\
Reset_TRESET TRESET_0/1/2←1

### 保持系(L)

Set_LHALT\
Reset_LHALT

### サイクル系(C)

Set_CM1\
Set_CMR\
Set_CMA\
Set_CBUSRQ\
Set_CRESET\
Set_CNMI\
Set_CINT0\
Set_CINT0_RST\
Set_CINT0_CALL\
Set_CINT1\
Set_CINT2\
Reset_CM1\
Reset_CMR\
Reset_CMA\
Reset_CBUSRQ\
Reset_CRESET\
Reset_CNMI\
Reset_CINT

### M1型命令系(X)

Set_XIX\
Set_XIX4_0/1\
Set_XIY\
Set_XIY4_0/1\
Set_XOTR\
Set_XBIT\
Reset_XIX\
Reset_XIX4\
Reset_XIY\
Reset_XIY4\
Reset_XOTR\
Reset_XBIT

### MR型命令系(I)

Set_ILDrn_A/B/C/D/E/H/L\
Set_ILDr(IX+d)_A/B/C/D/E/H/L\
Set_ILDr(IY+d)_A/B/C/D/E/H/L\
Set_ILD(IX+d)r_A/B/C/D/E/H/L\
Set_ILD(IY+d)r_A/B/C/D/E/H/L\
Set_ILD(HL)n\
Set_ILD(IX+d)n_0/1\
Set_ILD(IY+d)n_0/1\
Set_ILDA(nn)_0/1\
Set_ILD(nn)A_0/1\
Set_ILDddnn_BC/DE/HL/SP_0/1\
Set_ILDIXnn_0/1\
Set_ILDIYnn_0/1\
Set_ILDHL(nn)_0/1\
Set_ILDdd(nn)_BC/DE/HL/SP_0/1\
Set_ILDIX(nn)_0/1\
Set_ILDIY(nn)_0/1\
Set_ILD(nn)HL_0/1\
Set_ILD(nn)dd_BC/DE/HL/SP_0/1\
Set_ILD(nn)IX_0/1\
Set_ILD(nn)IY_0/1\
Set_IADDAn\
Set_IADDA(IX+d)\
Set_IADDA(IY+d)\
Set_IADCAn\
Set_IADCA(IX+d)\
Set_IADCA(IY+d)\
Set_ISUBAn\
Set_ISUBA(IX+d)\
Set_ISUBA(IY+d)\
Set_ISBCAn\
Set_ISBCA(IX+d)\
Set_ISBCA(IY+d)\
Set_IANDn\
Set_IAND(IX+d)\
Set_IAND(IY+d)\
Set_IORn\
Set_IOR(IX+d)\
Set_IOR(IY+d)\
Set_IXORn\
Set_IXOR(IX+d)\
Set_IXOR(IY+d)\
Set_ICPn\
Set_ICP(IX+d)\
Set_ICP(IY+d)\
Set_IINC(IX+d)\
Set_IINC(IY+d)\
Set_IDEC(IX+d)\
Set_IDEC(IY+d)\
Set_IJPnn_0/1\
Set_IJPccnn_0/1/2/3/4/5/6/7_0/1\
Set_IJRe\
Set_IJRCe\
Set_IJRNCe\
Set_IJRZe\
Set_IJRNZe\
Set_IDJNZe\
Set_ICALLnn_0/1\
Set_ICALLccnn_0/1/2/3/4/5/6/7_0/1\
Set_IINA(n)\
Set_IOUT(n)A\
Reset_ITABLE

### その他

Reset_ALLUNOFFICIALFF: CRESET以外の非公式フリップフロップをオールクリアする

## ALU (PA){#pf-pa}

### 入力

Select_A_high\
Select_B_high\
Select_C_high\
Select_D_high\
Select_E_high\
Select_H_high\
Select_L_high\
Select_Dt_high\
Select_BC_high\
Select_DE_high\
Select_HL_high\
Select_PC_high\
Select_SP_high\
Select_IX_high\
Select_IY_high\
Select_0x0_high\
Select_0x1_high\
Select_A_low\
Select_F_low\
Select_B_low\
Select_C_low\
Select_D_low\
Select_E_low\
Select_H_low\
Select_L_low\
Select_Dt_low\
Select_Dtcs_low\
Select_Din_low\
Select_R_low\
Select_I_low\
Select_OP_low\
Select_BC_low\
Select_DE_low\
Select_HL_low\
Select_PC_low\
Select_SP_low\
Select_IX_low\
Select_IY_low\
Select_IOP_low\
Select_OPOPold_low\
Select_0xffOP_low\
Select_OPxx_low\
Select_0x0_low\
Select_0x1_low\
Select_0x8_low\
Select_0x10_low\
Select_0x18_low\
Select_0x20_low\
Select_0x28_low\
Select_0x30_low\
Select_0x38_low\
Select_0x66_low\
Select_0x99_low\
Select_0x06_low\
Select_0x60_low\
Select_0x2_low\
Select_0x4_low\
Select_0x40_low\
Select_0x80_low

### 演算

NOP\
ADD\
ADC\
SUB\
SBC\
AND\
NLAND\
OR\
XOR\
NOT\
RLC\
RL\
RRC\
RR\
SLA\
SRA\
SRL\
RLD\
RRD

## インターフェース (PI){#pf-pi}

### トライステート

Activate_Ad_high\
Activate_Ad_low\
Activate_Dt\
Nullify_MREQ\
Nullify_RD\
Nullify_WR\
Nullify_IORQ

### アドレスバス

SelectAd_PC\
SelectAd_SP\
SelectAd_BC\
SelectAd_DE\
SelectAd_IR\
SelectAd_HL\
SelectAd_DtexDt\
SelectAd_OPOPold\
SelectAd_ALU\
SelectAd_AOP

### データバス

SelectDt_PC_high\
SelectDt_PC_low\
SelectDt_IX_high\
SelectDt_IX_low\
SelectDt_IY_high\
SelectDt_IY_low\
SelectDt_A\
SelectDt_F\
SelectDt_B\
SelectDt_C\
SelectDt_D\
SelectDt_E\
SelectDt_H\
SelectDt_L\
SelectDt_OP\
SelectDt_Dt\
SelectDt_Dtex

### その他

ReadDtcs: Dtcs←Din\
SelectAd+1: アドレスバスを+1する\
Flag_MREQ\
Flag_RD\
Flag_WR\
Flag_RFSH\
Flag_IORQ\
Flag_M1\
Flag_BUSACK\
Flag_HALT

## 半遅延インターフェース (PhI){#pf-phi}

Activate_Dt\
Flag_MREQ\
Flag_RD\
Flag_WR\
Flag_RFSH\
Flag_IORQ\
Flag_M1\
Flag_BUSACK

## 遅延 (Pa){#pf-pai}

Ophd (命令の先頭であることを表す)

<br>
{{<line>}}

## ALU{#alu}

## 演算{#alu-operation}

### NOP

### ADD

high + low

### ADC

high + low + Flag_C

### SUB

high + NOT(low) + 1

### SBC

high + NOT(low) + !Flag_C

### AND

### NLAND

{ high }AND{ NOT(low) }

### OR

### XOR

### NOT

### RLC

\[low_6,…,low_0,low_7\]

### RL

\[low_6,…,low_0,Flag_C\]

### RRC

\[low_0,low_7,…,low_1\]

### RR

\[Flag_C,low_7,…,low_1\]

### SLA

\[low_6,…,low_0,0\]

### SRA

\[low_7,low_7,…,low_1\]

### SRL

\[0,low_7,…,low_1\]

### RLD

low_0\~3→high_0\~3→high_4\~7→low_0\~3

### RRD

low_0\~3→high_4\~7→high_0\~3→low_0\~3

## 出力バス{#alu-bus}

{{<table2HR>}}
A: bit
B: 
items:
    - a: 0~15
      b: 演算結果
    - a: (16)
      b: 0
    - a: (17)
      b: 1
    - a: (18)
      b: IFF2{AND}CINT
    - a: 19
      b: is8bitEqual
    - a: 20
      b: notIs16bitEqual
    - a: 21
      b: HCY(4つめの全加算機から5つめへのcarry)
    - a: (22)
      b: ハーフボロー not(HCY)のこと
    - a: 23
      b: CY(8つ目からのキャリー)
    - a: 24
      b: isResultLow0
    - a: 25
      b: is8bitOverFlow
    - a: (26)
      b: ボロー
    - a: 27
      b: is8bitEvenParity
    - a: 28
      b: DAA_Flag_H
    - a: (29)
      b: Flag_S or Flag_C
    - a: (30)
      b: Flag_C
    - a: 31
      b: 16bitハーフキャリー(12から)
    - a: 32
      b: 16bitキャリー(16から)
    - a: 33
      b: is16bitOverFlow
    - a: 34
      b: isResult0
    - a: (35)
      b: 16bitハーフボロー
    - a: (36)
      b: 16bitボロー
    - a: 37
      b: inputLow0
    - a: 38
      b: inputLow7
    - a: 39
      b: DAACY
    - a: (40~55)
      b: Not(演算結果)
{{</table2HR>}}

### 19 is8bitEqual

\[low_0\~7\] == \[high_0\~7\]

### 21 ハーフキャリー

4つ目の全加算器からのキャリー

### 22 ハーフボロー

!ハーフキャリー

### 25 is8bitOverFlow

{{<table4HM>}}
A: high_7
B: low_7
C: result_7
D: V
items:
    - a: 1
      b: 1
      c: 0
      d: 1
    - a: 0
      b: 0
      c: 1
      d: 1
{{</table4HM>}}

SUB/SBC はNOT処理をしたlowで比較する

### 27 is8bitEvenParity

result_0\~7における bit**1** の数が偶数

### 28 DAA_Flag_H

{ high_4 }XOR{ result_4 }

### 39 DAACY

(ALU_High = 1xx1xxxx and CY4) or CY8

<br>
{{<line>}}

## デコーダ{#decoder}

デコーダ

正しい書き方がわからないので\... いまいち分かりにくいかもしれません。

## 標準サイクル{#basecycle}

### M1(4){#bc-m1}

{{<table4R>}}
- a: 0
  b: M1
  c: cl↑
  d: PI_Activate_Ad_high\PI_Activate_Ad_low\PI_SelectAd_PC\PI_Flag_M1
- a: 
  b: 
  c: cl↓
  d: PhI_Flag_MREQ\PhI_Flag_RD
- a: 1(W)
  b: 
  c: cl↑
  d: PI_Activate_Ad_high\PI_Activate_Ad_low\PI_SelectAd_PC\PI_Flag_M1\PI_Flag_MREQ\PI_Flag_RD\PA_Select_Din_low\PA_NOP\if(WAIT)→PR_Write_OP\　　　　　PI_SlideOP\if(/WAIT)→PR_Halt_XPT
- a: 
  b: 
  c: cl↓
  d: 
- a: 2
  b: 
  c: cl↑
  d: PI_Activate_Ad_high\PI_Activate_Ad_low\PI_SelectAd_IR\PI_Flag_RFSH\(PR_Inc_PC)
- a: 
  b: 
  c: cl↓
  d: PhI_Flag_MREQ
- a: 3
  b: 
  c: cl↑
  d: P2_Reset_CM1\PI_Activate_Ad_high\PI_Activate_Ad_low\PI_SelectAd_IR\PI_Flag_RFSH\PR_Inc_R
- a: 
  b: 
  c: cl↓
  d: 
{{</table4R>}}

### MR (3){#bc-mr}

{{<table4R>}}
- a: 0
  b: MR
  c: cl↑
  d: PI_Activate_Ad_high\PI_Activate_Ad_low\PI_SelectAd_PC
- a: 
  b: 
  c: cl↓
  d: PhI_Flag_MREQ\PhI_Flag_RD
- a: 1(W)
  b: 
  c: cl↑
  d: PI_Activate_Ad_high\PI_Activate_Ad_low\PI_SelectAd_PC\if(/TWAIT)→PR_Halt_XPT
- a: 
  b: 
  c: cl↓
  d: PhI_Flag_MREQ\PhI_Flag_RD
- a: 2
  b: 
  c: cl↑
  d: PI_Activate_Ad_high\PI_Activate_Ad_low\PI_SelectAd_PC\PI_Read_Dtcs\PR_SlideOP\PA_Select_Dtcs_low\PA_NOP\PR_Write_OP\P2_Reset_CMR\if(!CINT0_CALL)→PR_Inc_PC
- a: 
  b: 
  c: cl↓
  d: 
{{</table4R>}}

### MA (3){#bc-ma}

{{<table4R>}}
- a: 0
  b: MR
  c: cl↑
  d: PI_Activate_Ad_high\PI_Activate_Ad_low\PI_SelectAd_PC
- a: 
  b: 
  c: cl↓
  d: PhI_Flag_MREQ\PhI_Flag_RD
- a: 1(W)
  b: 
  c: cl↑
  d: PI_Activate_Ad_high\PI_Activate_Ad_low\PI_SelectAd_PC\if(/TWAIT)→PR_Halt_XPT
- a: 
  b: 
  c: cl↓
  d: PhI_Flag_MREQ\PhI_Flag_RD
- a: 2
  b: 
  c: cl↑
  d: PI_Activate_Ad_high\PI_Activate_Ad_low\PI_SelectAd_PC\PI_Read_Dtcs\(PA_Select_???_high)\PA_Select_Dtcs_low\(PA_???)\(PR_Write_???)\(?PR_InvertIn)\PR_Inc_PC\P2_Reset_CMA
- a: 
  b: 
  c: cl↓
  d: 
{{</table4R>}}

### R (3){#bc-r}

{{<table4R>}}
- a: 0
  b: R
  c: cl↑
  d: PI_Activate_Ad_high\PI_Activate_Ad_low\(PI_SelectAd_???)
- a: 
  b: 
  c: cl↓
  d: PhI_Flag_MREQ\PhI_Flag_RD
- a: 1(W)
  b: 
  c: cl↑
  d: PI_Activate_Ad_high\PI_Activate_Ad_low\(PI_SelectAd_???)\if(/TWAIT)→PR_Halt_XPT
- a: 
  b: 
  c: cl↓
  d: PhI_Flag_MREQ\PhI_Flag_RD
- a: 2
  b: 
  c: cl↑
  d: PI_Activate_Ad_high\PI_Activate_Ad_low\(PI_SelectAd_???)\PI_Read_Dtcs\PA_Select_Dtcs_low\PA_NOP\(PR_Write_???)\(?PR_InvertIn)
- a: 
  b: 
  c: cl↓
  d: 
{{</table4R>}}

### RA (3){#bc-ra}

{{<table4R>}}
- a: 0
  b: R
  c: cl↑
  d: PI_Activate_Ad_high\PI_Activate_Ad_low\(PI_SelectAd_???)
- a: 
  b: 
  c: cl↓
  d: PhI_Flag_MREQ\PhI_Flag_RD
- a: 1(W)
  b: 
  c: cl↑
  d: PI_Activate_Ad_high\PI_Activate_Ad_low\(PI_SelectAd_???)\if(/TWAIT)→PR_Halt_XPT
- a: 
  b: 
  c: cl↓
  d: PhI_Flag_MREQ\PhI_Flag_RD
- a: 2
  b: 
  c: cl↑
  d: PI_Activate_Ad_high\PI_Activate_Ad_low\(PI_SelectAd_???)\PI_Read_Dtcs\(PA_Select_???_high)\PA_Select_Dtcs_low\(PA_???)\(PR_Write_???)\(?PR_InvertIn)
- a: 
  b: 
  c: cl↓
  d: 
{{</table4R>}}

### W (3){#bc-w}

{{<table4R>}}
- a: 0
  b: W
  c: cl↑
  d: PI_Activate_Ad_high\PI_Activate_Ad_low\(PI_SelectAd_???)\(PI_SelectDt_???)
- a: 
  b: 
  c: cl↓
  d: PhI_Flag_MREQ\PhI_Activate_Dt
- a: 1(W)
  b: 
  c: cl↑
  d: PI_Activate_Ad_high\PI_Activate_Ad_low\(PI_SelectAd_???)\PI_Activate_Dt\(PI_SelectDt_???)\if(/TWAIT)→PR_Halt_XPT
- a: 
  b: 
  c: cl↓
  d: PhI_Flag_MREQ\PhI_Flag_WR
- a: 2
  b: 
  c: cl↑
  d: PI_Activate_Ad_high\PI_Activate_Ad_low\(PI_SelectAd_???)\PI_Activate_Dt\(PI_Select_Dt_???)
- a: 
  b: 
  c: cl↓
  d: 
{{</table4R>}}

### I (4){#bc-i}

{{<table4R>}}
- a: 0
  b: I
  c: cl↑
  d: PI_Activate_Ad_high\PI_Activate_Ad_low\(PI_SelectAd_???)
- a: 
  b: 
  c: cl↓
  d: 
- a: 1
  b: 
  c: cl↑
  d: PI_Activate_Ad_high\PI_Activate_Ad_low\(PI_SelectAd_???)\PI_Flag_IORQ\PI_Flag_RD
- a: 
  b: 
  c: cl↓
  d: 
- a: 2(W)
  b: 
  c: cl↑
  d: PI_Activate_Ad_high\PI_Activate_Ad_low\(PI_SelectAd_???)\PI_Flag_IORQ\PI_Flag_RD\if(/TWAIT)→PR_Halt_XPT
- a: 
  b: 
  c: cl↓
  d: PhI_Flag_IORQ\PhI_Flag_RD
- a: 3
  b: 
  c: cl↑
  d: PI_Activate_Ad_high\PI_Activate_Ad_low\(PI_SelectAd_???)\PI_Read_Dtcs\PA_Select_Dtcs_low\PA_NOP\(PR_Write_???)\(?PR_InvertIn)
- a: 
  b: 
  c: cl↓
  d: 
{{</table4R>}}
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

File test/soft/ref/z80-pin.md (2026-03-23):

DoutはData信号のZ80からの出力信号が出ているもの
Z80からのDataを読み込む時にDoutを使うかDを使うかはオプションで切り替えられるようにすること

| 種類 | io | とりうる値 | デフォルト値 | 名前 |
|---|---|---|---|---|
| アドレスバス | out | 1/0/Z | Z | A0~A15 |
| データバス | in/out | 1/0/Z | Z | D0~D7 |
| バス制御 | in | | | /BUSRQ |
| | out | 1/0 | 1 | BUSAK |
| 主記憶制御 | out | 1/0/Z | 1 | /MREQ |
| | out | 1/0/Z | 1 | /RD |
| | out | 1/0/Z | 1 | /WR |
| | out | 1/0 | 1 | /RFSH |
| 入出力制御 | out | 1/0/Z | 1 | /IORQ |
| その他の制御 | out | 1/0 | 1 | /M1 |
| | in | | | /RESET |
| | in | | | /WAIT |
| | out | 1/0 | 1 | /HALT |
| 割り込み入力 | in | | | /NMI |
| | in | | | /INT |
| クロック | in | | | /CLK |
| 電源 | in | | | VCC(5V)  |
| | in | | | GND |

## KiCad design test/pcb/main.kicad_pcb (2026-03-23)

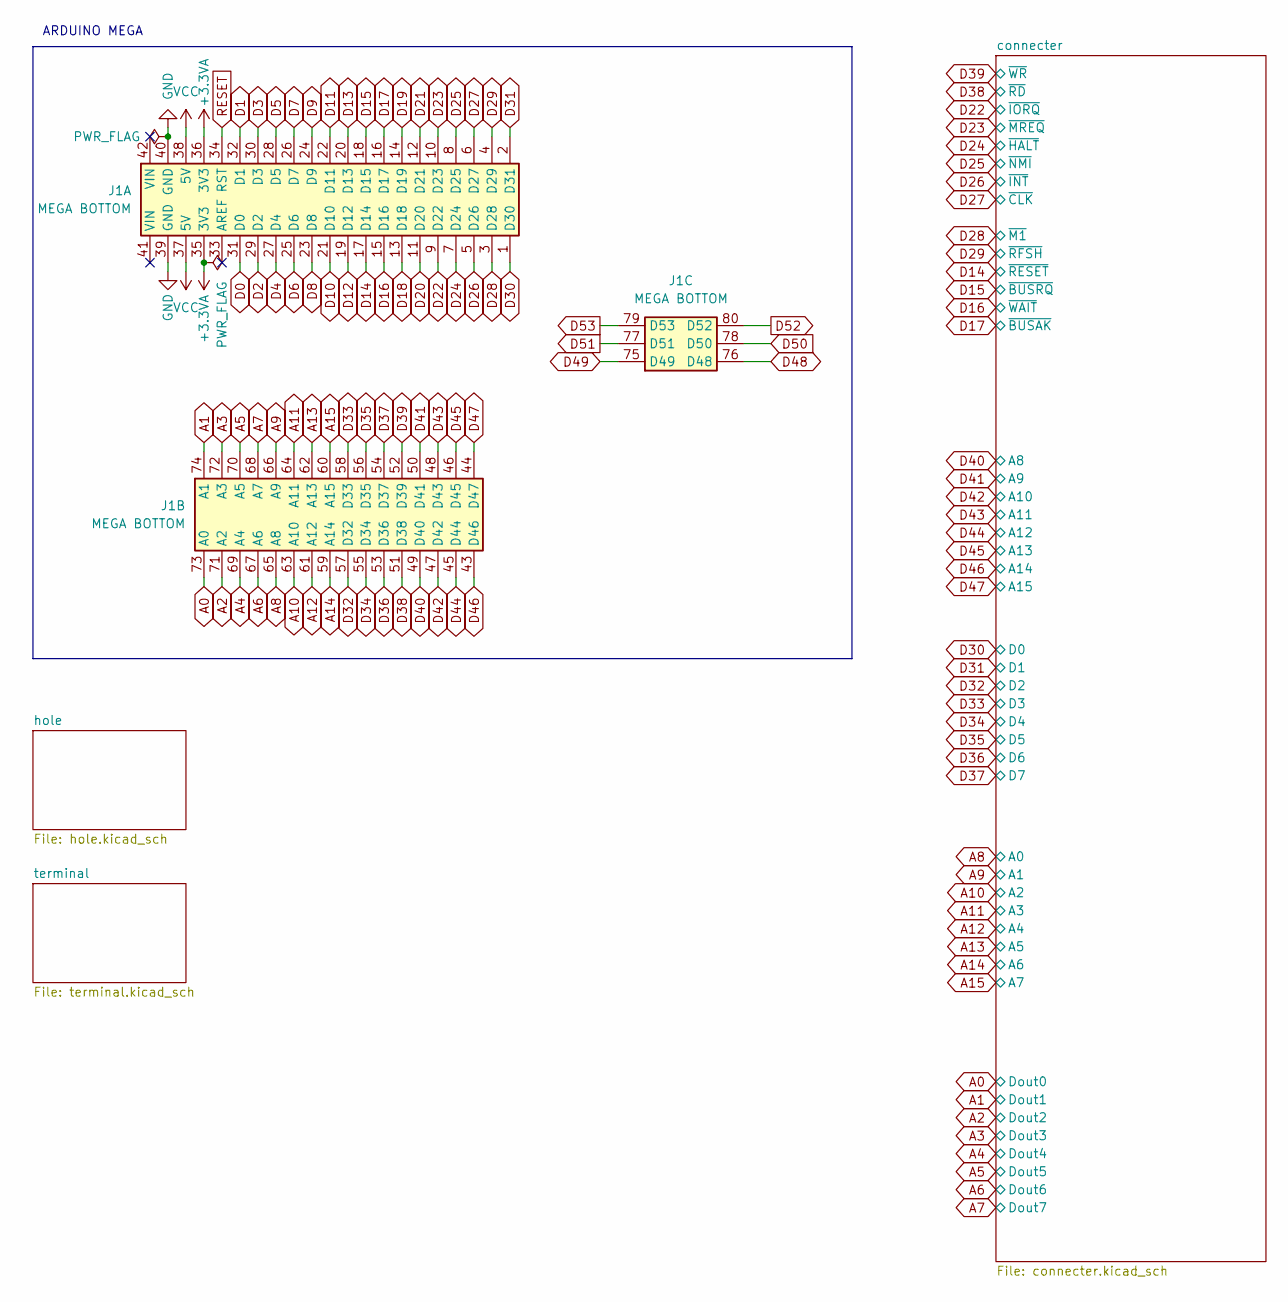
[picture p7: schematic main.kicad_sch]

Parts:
J1: MEGA BOTTOM; MEGA2560_PRO_MINI

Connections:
+3.3VA: J1.35 (3V3), J1.36 (3V3)
A0: J1.73 (A0); also elsewhere on the board
A1: J1.74 (A1); also elsewhere on the board
A2: J1.71 (A2); also elsewhere on the board
A3: J1.72 (A3); also elsewhere on the board
A4: J1.69 (A4); also elsewhere on the board
A5: J1.70 (A5); also elsewhere on the board
A6: J1.67 (A6); also elsewhere on the board
A7: J1.68 (A7); also elsewhere on the board
A8: J1.65 (A8); also elsewhere on the board
A9: J1.66 (A9); also elsewhere on the board
A10: J1.63 (A10); also elsewhere on the board
A11: J1.64 (A11); also elsewhere on the board
A12: J1.61 (A12); also elsewhere on the board
A13: J1.62 (A13); also elsewhere on the board
A14: J1.59 (A14); also elsewhere on the board
A15: J1.60 (A15); also elsewhere on the board
D0: J1.31 (D0)
D1: J1.32 (D1)
D2: J1.29 (D2)
D3: J1.30 (D3)
D4: J1.27 (D4)
D5: J1.28 (D5)
D6: J1.25 (D6)
D7: J1.26 (D7)
D8: J1.23 (D8)
D9: J1.24 (D9)
D10: J1.21 (D10)
D11: J1.22 (D11)
D12: J1.19 (D12)
D13: J1.20 (D13)
D14: J1.17 (D14); also elsewhere on the board
D15: J1.18 (D15); also elsewhere on the board
D16: J1.15 (D16); also elsewhere on the board
D17: J1.16 (D17); also elsewhere on the board
D18: J1.13 (D18)
D19: J1.14 (D19)
D20: J1.11 (D20)
D21: J1.12 (D21)
D22: J1.9 (D22); also elsewhere on the board
D23: J1.10 (D23); also elsewhere on the board
D24: J1.7 (D24); also elsewhere on the board
D25: J1.8 (D25); also elsewhere on the board
D26: J1.5 (D26); also elsewhere on the board
D27: J1.6 (D27); also elsewhere on the board
D28: J1.3 (D28); also elsewhere on the board
D29: J1.4 (D29); also elsewhere on the board
D30: J1.1 (D30); also elsewhere on the board
D31: J1.2 (D31); also elsewhere on the board
D32: J1.57 (D32); also elsewhere on the board
D33: J1.58 (D33); also elsewhere on the board
D34: J1.55 (D34); also elsewhere on the board
D35: J1.56 (D35); also elsewhere on the board
D36: J1.53 (D36); also elsewhere on the board
D37: J1.54 (D37); also elsewhere on the board
D38: J1.51 (D38); also elsewhere on the board
D39: J1.52 (D39); also elsewhere on the board
D40: J1.49 (D40); also elsewhere on the board
D41: J1.50 (D41); also elsewhere on the board
D42: J1.47 (D42); also elsewhere on the board
D43: J1.48 (D43); also elsewhere on the board
D44: J1.45 (D44); also elsewhere on the board
D45: J1.46 (D45); also elsewhere on the board
D46: J1.43 (D46); also elsewhere on the board
D47: J1.44 (D47); also elsewhere on the board
D48: J1.76 (D48)
D49: J1.75 (D49)
D50: J1.78 (D50)
D51: J1.77 (D51)
D52: J1.80 (D52)
D53: J1.79 (D53)
GND: J1.39 (GND), J1.40 (GND); also elsewhere on the board
RESET: J1.34 (RST)
VCC: J1.37 (5V), J1.38 (5V); also elsewhere on the board

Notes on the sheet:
ARDUINO MEGA

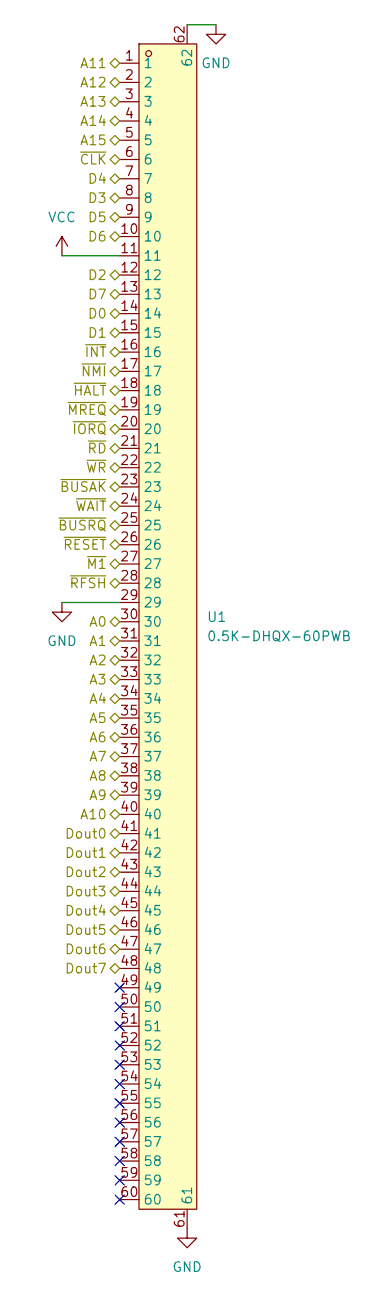
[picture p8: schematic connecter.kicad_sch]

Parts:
U1: 0.5K-DHQX-60PWB; FPC-SMD_60P-P0.50_HDGC_0.5K-DHQX-60PWB; LCSC Part C5292476

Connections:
A0: U1.41; also elsewhere on the board
A1: U1.42; also elsewhere on the board
A2: U1.43; also elsewhere on the board
A3: U1.44; also elsewhere on the board
A4: U1.45; also elsewhere on the board
A5: U1.46; also elsewhere on the board
A6: U1.47; also elsewhere on the board
A7: U1.48; also elsewhere on the board
A8: U1.30; also elsewhere on the board
A9: U1.31; also elsewhere on the board
A10: U1.32; also elsewhere on the board
A11: U1.33; also elsewhere on the board
A12: U1.34; also elsewhere on the board
A13: U1.35; also elsewhere on the board
A14: U1.36; also elsewhere on the board
A15: U1.37; also elsewhere on the board
D14: U1.26; also elsewhere on the board
D15: U1.25; also elsewhere on the board
D16: U1.24; also elsewhere on the board
D17: U1.23; also elsewhere on the board
D22: U1.20; also elsewhere on the board
D23: U1.19; also elsewhere on the board
D24: U1.18; also elsewhere on the board
D25: U1.17; also elsewhere on the board
D26: U1.16; also elsewhere on the board
D27: U1.6; also elsewhere on the board
D28: U1.27; also elsewhere on the board
D29: U1.28; also elsewhere on the board
D30: U1.14; also elsewhere on the board
D31: U1.15; also elsewhere on the board
D32: U1.12; also elsewhere on the board
D33: U1.8; also elsewhere on the board
D34: U1.7; also elsewhere on the board
D35: U1.9; also elsewhere on the board
D36: U1.10; also elsewhere on the board
D37: U1.13; also elsewhere on the board
D38: U1.21; also elsewhere on the board
D39: U1.22; also elsewhere on the board
D40: U1.38; also elsewhere on the board
D41: U1.39; also elsewhere on the board
D42: U1.40; also elsewhere on the board
D43: U1.1; also elsewhere on the board
D44: U1.2; also elsewhere on the board
D45: U1.3; also elsewhere on the board
D46: U1.4; also elsewhere on the board
D47: U1.5; also elsewhere on the board
GND: U1.29, U1.61, U1.62; also elsewhere on the board
VCC: U1.11; also elsewhere on the board

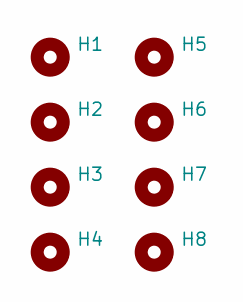
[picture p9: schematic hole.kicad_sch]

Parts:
H1, H2, H3, H4: MountingHole_3.2mm_M3_ISO7380; LCSC XXX
H5, H6, H7, H8: toolinghole; LCSC XXX

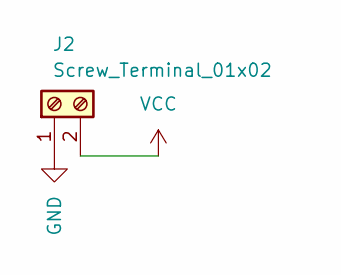
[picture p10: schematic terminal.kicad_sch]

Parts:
J2: Screw_Terminal_01x02; TerminalBlock_bornier-2_P5.08mm; LCSC XXX

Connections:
GND: J2.1; also elsewhere on the board
VCC: J2.2; also elsewhere on the board

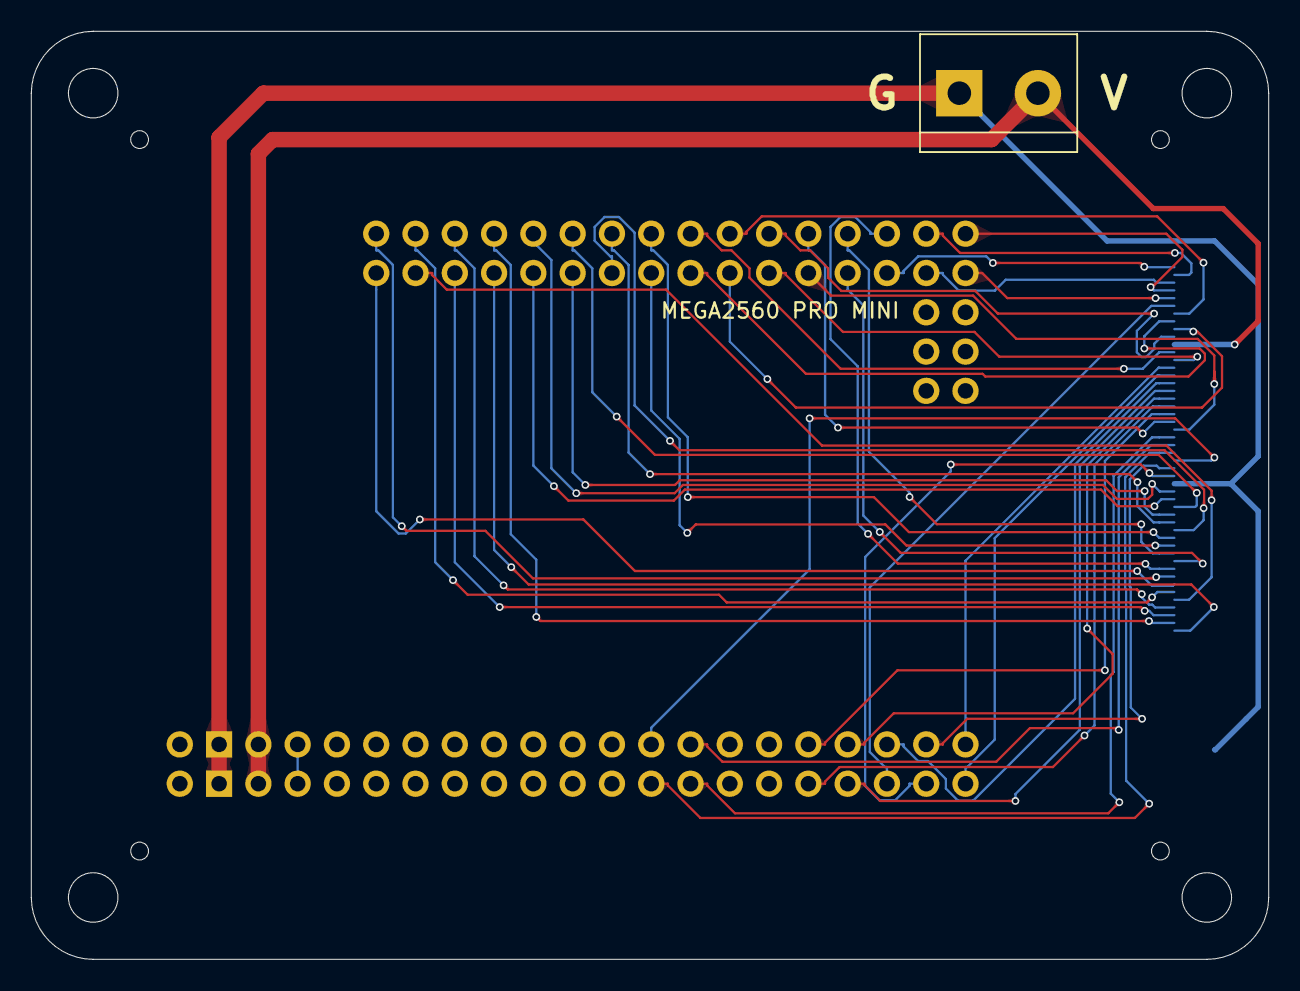
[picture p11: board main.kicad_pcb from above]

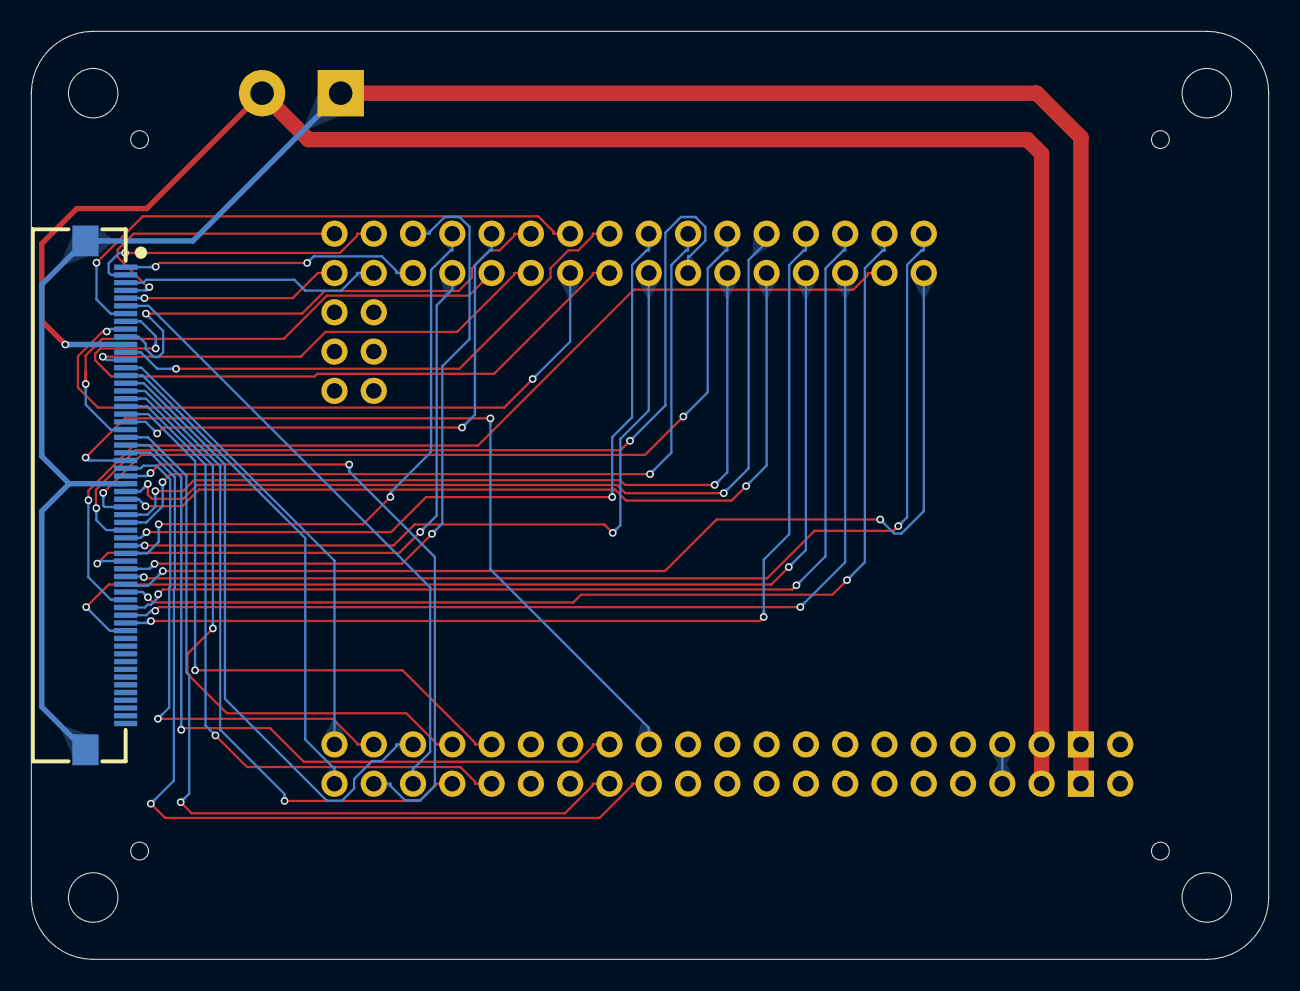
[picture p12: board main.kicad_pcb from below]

Board: 2 copper layers, 80.0 x 60.0 mm, 11 parts (2 on the bottom side), 49 nets.

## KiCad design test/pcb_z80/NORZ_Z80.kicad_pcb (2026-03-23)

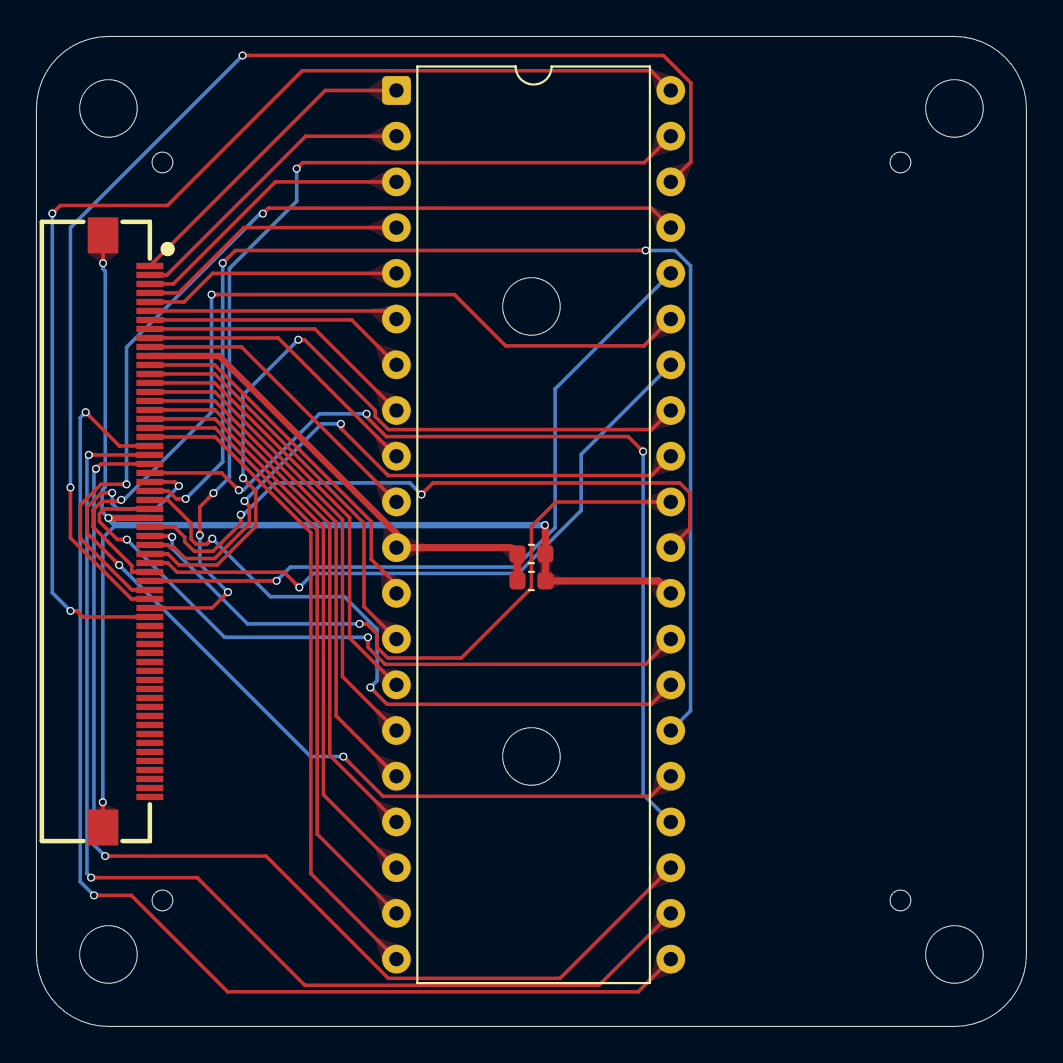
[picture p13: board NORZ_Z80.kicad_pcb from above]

Board: 2 copper layers, 55.0 x 55.0 mm, 14 parts (0 on the bottom side), 40 nets.

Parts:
C1: 100nF; C_0603_1608Metric
C2: 22nF; C_0603_1608Metric
H1, H2, H3, H4, H9, H10: MountingHole_3.2mm_M3_ISO7380
H5, H6, H7, H8: toolinghole
U1: 0.5K-DHQX-60PWB; FPC-SMD_60P-P0.50_HDGC_0.5K-DHQX-60PWB
U2: Z84C00xxP; DIP-40_W15.24mm

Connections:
+5V: C1.1, C2.1, U1.11, U2.11 (V_{CC})
/connecter/A0: U1.30, U2.30 (A_{0})
/connecter/A1: U1.31, U2.31 (A_{1})
/connecter/A2: U1.32, U2.32 (A_{2})
/connecter/A3: U1.33, U2.33 (A_{3})
/connecter/A4: U1.34, U2.34 (A_{4})
/connecter/A5: U1.35, U2.35 (A_{5})
/connecter/A6: U1.36, U2.36 (A_{6})
/connecter/A7: U1.37, U2.37 (A_{7})
/connecter/A8: U1.38, U2.38 (A_{8})
/connecter/A9: U1.39, U2.39 (A_{9})
/connecter/A10: U1.40, U2.40 (A_{10})
/connecter/A11: U1.1, U2.1 (A_{11})
/connecter/A12: U1.2, U2.2 (A_{12})
/connecter/A13: U1.3, U2.3 (A_{13})
/connecter/A14: U1.4, U2.4 (A_{14})
/connecter/A15: U1.5, U2.5 (A_{15})
/connecter/D0: U1.14, U2.14 (D_{0})
/connecter/D1: U1.15, U2.15 (D_{1})
/connecter/D2: U1.12, U2.12 (D_{2})
/connecter/D3: U1.8, U2.8 (D_{3})
/connecter/D4: U1.7, U2.7 (D_{4})
/connecter/D5: U1.9, U2.9 (D_{5})
/connecter/D6: U1.10, U2.10 (D_{6})
/connecter/D7: U1.13, U2.13 (D_{7})
/connecter/~BUSAK: U1.23, U2.23 (~BUSACK)
/connecter/~BUSRQ: U1.25, U2.25 (~BUSREQ)
/connecter/~CLK: U1.6, U2.6 (CLK)
/connecter/~HALT: U1.18, U2.18 (~HALT)
/connecter/~INT: U1.16, U2.16 (~INT)
/connecter/~IORQ: U1.20, U2.20 (~IORQ)
/connecter/~M1: U1.27, U2.27 (~M1)
/connecter/~MREQ: U1.19, U2.19 (~MREQ)
/connecter/~NMI: U1.17, U2.17 (~NMI)
/connecter/~RD: U1.21, U2.21 (~RD)
/connecter/~RESET: U1.26, U2.26 (~RESET)
/connecter/~RFSH: U1.28, U2.28 (~RFSH)
/connecter/~WAIT: U1.24, U2.24 (~WAIT)
/connecter/~WR: U1.22, U2.22 (~WR)
GND: C1.2, C2.2, U1.29, U1.61, U1.62, U2.29 (GND)
